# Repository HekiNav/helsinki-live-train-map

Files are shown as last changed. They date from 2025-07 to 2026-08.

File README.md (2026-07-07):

# Helsinki Live LED Train Map

A real-time PCB map of the Helsinki Region train network, powered by an ESP32-C3 microcontroller. Train movements are displayed using addressable RGB LEDs, with live data fetched over Wi-Fi.

---

## Table of Contents

- [Helsinki Live LED Train Map](#helsinki-live-led-train-map)
  - [Table of Contents](#table-of-contents)
  - [Features](#features)
  - [Hardware](#hardware)
  - [Design](#design)
  - [Software / Firmware](#software--firmware)
  - [Getting Started](#getting-started)
  - [Web Installer](#web-installer)
  - [Web Simulator](#web-simulator)
  - [Stand](#stand)
  - [Server](#server)
  - [Links](#links)
  - [Contributing](#contributing)
  - [License](#license)

---

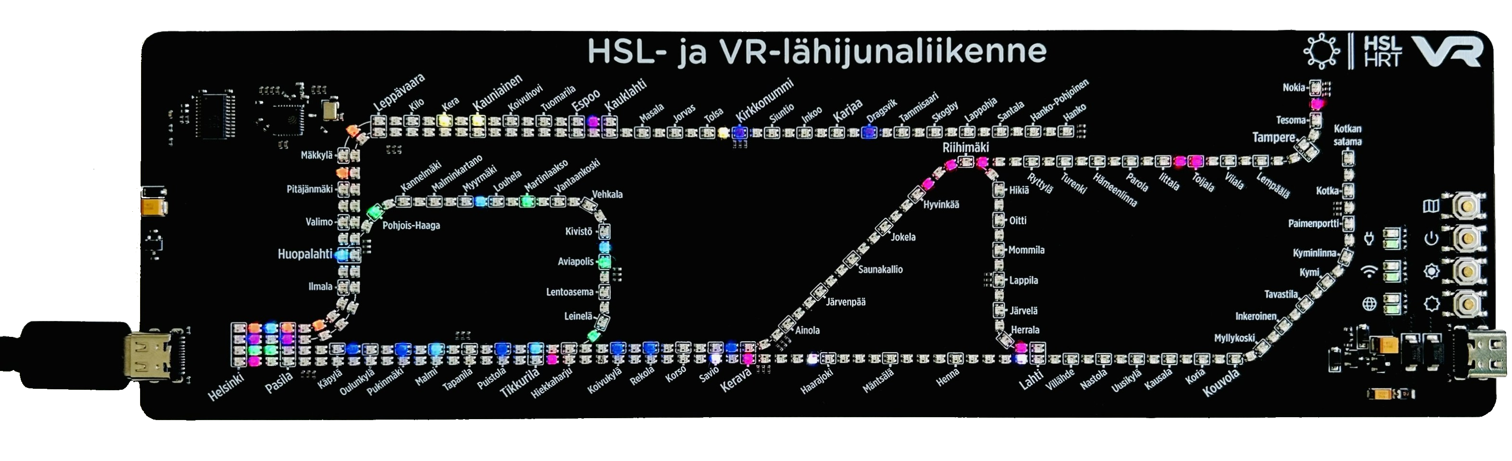
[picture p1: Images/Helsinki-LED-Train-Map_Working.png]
PCB Overview Render


## Features

- **Real-time Train Tracking:** Displays the approximate locations of trains on the HSL and VR commuter network.
- **Addressable LEDs:** ~290 WS2812B-compatible RGB LEDs (1.6x1.5mm) for a vibrant display.
- **Wi-Fi Connectivity:** ESP32-C3's built-in Wi-Fi fetches live train data.
- **Custom PCB:** Designed for JLCPCB manufacturing limits.
- **Open Source:** Hardware and firmware are open source.

---

## Hardware

- **Microcontroller:** Expressif ESP32-C3FH4 (RISC-V, 160 MHz, 4 MB Flash, QFN32)
- **Level shifter:** Texas Instruments SN74LVC4245APWR (3.3V to 5V)
- **LEDs:** ~290 x XingLight XL-1615RGBC-WS2812B (1.6mm x 1.5mm)
- **PCB:** 249mm x 71.5mm, JLCPCB-friendly
- **Antenna:** On-board PCB antenna ([TI CC2430DB design](https://www.ti.com/lit/ug/swru125/swru125.pdf))
- **Ports:** Two USB Type-C ports for redundancy

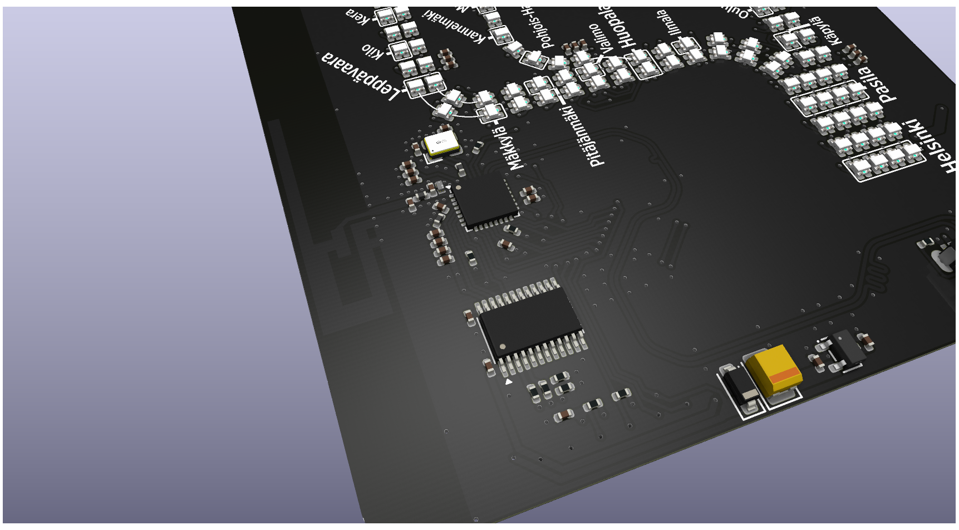
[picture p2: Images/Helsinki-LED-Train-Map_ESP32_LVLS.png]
ESP32-C3 PCB Render


---

## Design

### Rail diagram design

Inspiration for the layout was taken from the VR rail map used on commuter trains (above the doors). 

**Each LED represents a double-track line**
- 8-tracked sections (4 LEDs wide):
   1. Helsinki-Pasila
- Quad-tracked sections (2 express commuter & intercity, 2 slower commuter):
   1. Pasila-Leppävaara-(Kauklahti [Under construction])
   2. Pasila-Kerava

- Exceptions to single-track lines: 
   1. Tavastila-Kotkan satama
   2. Siuntio-Hanko

### Technical design

- Designed in **KiCad V9.0** using [JLCPCB KiCad Library](https://github.com/CDFER/jlcpcb-kicad-library)
- **View Online:** [Interactive PCB Layout (Kicanvas)](https://kicanvas.org/?github=https%3A%2F%2Fgithub.com%2FHekiNav%2Fhelsinki-live-train-map%2Ftree%2Fmain%2FPCB)
- **Source Files:** `/PCB` directory
### Schematic
Led chains are located on other pages

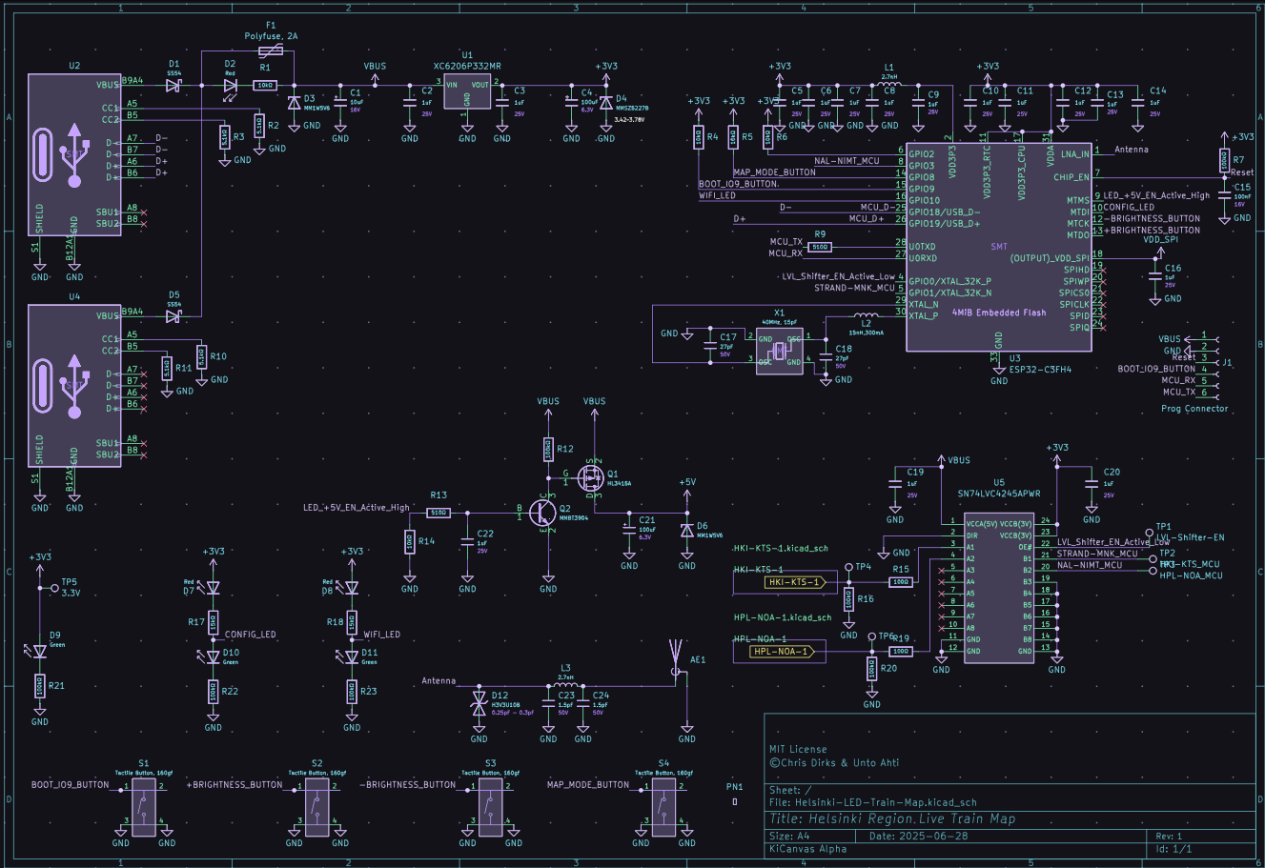
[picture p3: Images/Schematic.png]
Schematic


---

## Software / Firmware

NOTE! Software and firmware have been moved to [another repo](https://github.com/HekiNav/legacy-ltm-firmware)

The ESP32-C3 firmware is responsible for:

1. Connecting to Wi-Fi
2. Fetching live train data from the API
3. Processing data to determine train locations
4. Controlling WS2812B LED chains to display train positions
5. Handling button inputs and status LEDs
6. Hosting a web page for configuration

---

## Getting Started

1. **Flash the Firmware:**
   - Use the [Web Installer](#web-installer) (recommended, no drivers needed)
   - Or flash manually using PlatformIO (`Firmware/` directory)
2. **Connect to Wi-Fi:**
   - On first boot, use the web installer interface to configure Wi-Fi credentials. They are saved locally on the device.
3. **Power the Board:**
   - Use a 5V USB-C power supply capable of at least ~1A (~2A recommended for compatibility with higher brightness settings).
4. **Configure in the :**
   - Visit the IP address of your device (shown in Web Installer)
   - Configure options like tails, brightness and mode 
5. **Enjoy the Live Train Map!**

### Status LEDs

The top (🔌) power led is hardwired to the power rail

The middle and bottom status leds are controlled by the MCU

| LED | Light | Meaning |
|-----|---|---|
| top (🔌) |🟩 green | The board is powered
| top (🔌) |⬛ none  | The board is not powered
| top (🔌) |🟥 red | This shouldn't happen although it's techically possible if there's severe issues in the pcb
|||
| middle (ᯤ)  |🟩 green | Connected to the API
| middle (ᯤ)  |🟩 green \(blinking\) | Mode change pending
| middle (ᯤ)  |⬛ none | Connecting to the API
| middle (ᯤ)  |🟥 red | Failed to connect to API
|||
| bottom (🌐)  |🟩 green \(blinking\) | Connecting to wifi
| bottom (🌐)  |🟩 green | Connected to wifi
| bottom (🌐)  |⬛ none | Failed to boot
| bottom (🌐)  |🟥 red | Failed to connect to wifi

### Map Modes

There are 4(+1) map modes on the device. You can switch the mode by pressing the map (🗺️) button or by going to the control panel.

#### Lines (default)
- Shows commuter trains by line
- Only commuter trains
- Some colors are reused on lines that do not intersect

| Color | Line | |
|---|---|-|
|$${\color{#f00}\Huge\text{■}}$$| Z | |
|$${\color{#f80}\Huge\text{■}}$$| A | |
|$${\color{#ff0}\Huge\text{■}}$$| E,O | |
|$${\color{#0f0}\Huge\text{■}}$$| P,G | |
|$${\color{#0ff}\Huge\text{■}}$$| M,I | |
|$${\color{#00f}\Huge\text{■}}$$| K | |
|$${\color{#80f}\Huge\text{■}}$$| Y,L,H | |
|$${\color{#f0f}\Huge\text{■}}$$| U | |
|$${\color{#f08}\Huge\text{■}}$$| D,T,R | |
|$${\color{#fff}\Huge\text{■}}$$| V, Other | Look up on [juliadata.fi](https://juliadata.fi/map/view?mode=trains#8.86/60.3487/25.1733)|

\* V is used in transfer services

#### Delay
- Shows the delay state of trains
- Only commuter trains

| Color | Delay (min) | Description |
|---|---|---|
|$${\color{#0ff}\Huge\text{■}}$$| < 0 | Ahead of schedule |  
|$${\color{#0f0}\Huge\text{■}}$$| 0 - 2 | On time |
|$${\color{#ff0}\Huge\text{■}}$$| 2 - 10 | Mild delay |
|$${\color{#f00}\Huge\text{■}}$$| > 20 | Severe delay |
|$${\color{#f0f}\Huge\text{■}}$$| - | Unknown delay amount |

#### Composition
- Shows the locomotives/EMUs of trains
- ALL trains shown (incl. InterCity, freight)

| Color | Loco | Description |
|---|---|---|
| EMUs | | |
|$${\color{#f00}\Huge\text{■}}$$| [Sm2](https://fi.wikipedia.org/wiki/Sm2) | Commuter, old |
|$${\color{#0f0}\Huge\text{■}}$$| [Sm3](https://fi.wikipedia.org/wiki/Sm3) | Pendolino (IC) |
|$${\color{#ff0}\Huge\text{■}}$$| [Sm4](https://fi.wikipedia.org/wiki/Sm4) | Commuter, longer distances |
|$${\color{#80f}\Huge\text{■}}$$| [Sm5](https://fi.wikipedia.org/wiki/Sm5) | Commuter, shorter distances |
|$${\color{#f0f}\Huge\text{■}}$$| [Sm6](https://fi.wikipedia.org/wiki/Sm6) | Allegro (IC) |
|$${\color{#f80}\Huge\text{■}}$$| [Sm7](https://fi.wikipedia.org/wiki/Sm7) | Commuter, not in regular service yet |
| Locos | | |
|$${\color{#0ff}\Huge\text{■}}$$| [Sr2](https://fi.wikipedia.org/wiki/Sr2) | IC locomotive |
|$${\color{#00f}\Huge\text{■}}$$| [Sr3](https://fi.wikipedia.org/wiki/Sr3) | Newer IC locomotive |
| Other | | |
|$${\color{#f08}\Huge\text{■}}$$| N/A | No composition found (most likely freight) |
|$${\color{#fff}\Huge\text{■}}$$| Other | Other locomotive with no color defined (Look up on [juliadata.fi](https://juliadata.fi/map/view?mode=trains#8.86/60.3487/25.1733)) |

#### Train types
- Shows the types of trains
- ALL trains shown (incl. InterCity, freight)

| Color | Code | Description |
|---|---|---|
|$${\color{#f00}\Huge\text{■}}$$| IC | Double-decker intercity trains |
|$${\color{#f80}\Huge\text{■}}$$| VET | Locomotive train |
|$${\color{#f80}\Huge\text{■}}$$| MUS, MUV | Heritage train |
|$${\color{#0f0}\Huge\text{■}}$$| S | Pendolino train |
|$${\color{#00f}\Huge\text{■}}$$| T | Freight train |
|$${\color{#80f}\Huge\text{■}}$$| HL | Commuter train |
|$${\color{#f0f}\Huge\text{■}}$$| HV | Commuter train transfer |
|$${\color{#f08}\Huge\text{■}}$$| PAR, PAI, VEV, W, SAA | Shunting |
|$${\color{#fff}\Huge\text{■}}$$| Other | Other train type with no color defined (Look up on [juliadata.fi](https://juliadata.fi/map/view?mode=trains#8.86/60.3487/25.1733)) |

#### Test
- Shows the types of LEDs

| Color | Type | Description | Technical logic |
|---|---|---|---|
|$${\color{#ff0}\Huge\text{■}}$$| Station | All services stop | Train has arrived, but not departed |
|$${\color{#f00}\Huge\text{■}}$$| Stop | Express services skip | Same as station |
|$${\color{#0f0}\Huge\text{■}}$$| Between | Single LED between stops/stations | Train left previous, not arrived at next |
|$${\color{#0ff}\Huge\text{■}}$$| MultiBetween | Multiple LEDs between stops/stations | Same as between, but exact position is appoximated using timetable |

#### Disruptions
- Shows disruptions for stations and trains

| Color | Disruption |
|---|---|
|$${\color{#f00}\Huge\text{■}}$$| Cancellation |
|$${\color{#f80}\Huge\text{■}}$$| Infrastructure disruption |
|$${\color{#ff0}\Huge\text{■}}$$| Other disruption |
|$${\color{#0f0}\Huge\text{■}}$$| Track work |
|$${\color{#0ff}\Huge\text{■}}$$| Private train |
|$${\color{#00f}\Huge\text{■}}$$| Replacement service |
|$${\color{#80f}\Huge\text{■}}$$| Missing/replaced wagon(s) |
|$${\color{#fff}\Huge\text{■}}$$| Unclassified |

---

## Web Installer

Easily flash the latest firmware to your ESP32-C3 using your browser:

[Open the Helsinki LED Train Map Web Installer](https://hekinav.github.io/ltm-firmware/led-rails.html)

- Works with Chrome, Edge, or any Web Serial-compatible browser
- Follow on-screen instructions to connect and flash your device

---

## Web Simulator

View the map without having the physical pcb:

[Open the Helsinki LED Train Map Web Simulator](https://hekinav.github.io/ltm-firmware/sim.html)

- Use the map mode button to switch display modes, just like on the real thing
- Works with most modern browsers
- Fetches data from the API

---
## Stand and other 3D Models

A 3d-printable stand to hold up the board. Files are located in `/3D Models`

---

## Server

Processes train running data from [digitraffic](https://rata.digitraffic.fi/). Documentation for the train API is available at https://www.digitraffic.fi/rautatieliikenne. Most of it is only available in finnish.

### Main packages:
- express: API handling
- mqtt: Listening to MQTT train messages 
- node-sqlite & sqlite3: Database for cached train compositions and stats
- node-cron: Cron jobs for recaching data and cleaning the database

The api is tunneled to [ltm.hekinav.dev](https://ltm.hekinav.dev/).

### Running locally

Install npm packages

`npm install`

Start the api in dev mode (watches files) (uses port 3001 by default)

`npm run dev`

### Production

Compile TS to JS

`npm run build`

Start the server

`npm run start` or in PM2 `pm2 start ./ecosystem.config.cjs`

---

## Links

- [Web Installer](https://hekinav.github.io/ltm-firmware//led-rails.html)
- [Web Simulator](https://hekinav.github.io/ltm-firmware//sim.html)
- [Interactive PCB Viewer](https://kicanvas.org/?github=https%3A%2F%2Fgithub.com%2FHekiNav%2Fhelsinki-live-train-map%2Ftree%2Fmain%2FPCB)
- [JLCPCB KiCad Library](https://github.com/CDFER/jlcpcb-kicad-library)

---

## Contributing

Contributions are welcome! Open an issue or submit a pull request for improvements, bug fixes, or feature suggestions.

---

## Attributions

Thanks to [Chris (CDFER)](https://github.com/CDFER/) for the base and support of this project. Check out his store with multiple LED Rail Maps at [keastudios.co.nz](https://keastudios.co.nz/)

## License

This project is released under the MIT license.

© 2025 Chris Dirks & Unto Ahti

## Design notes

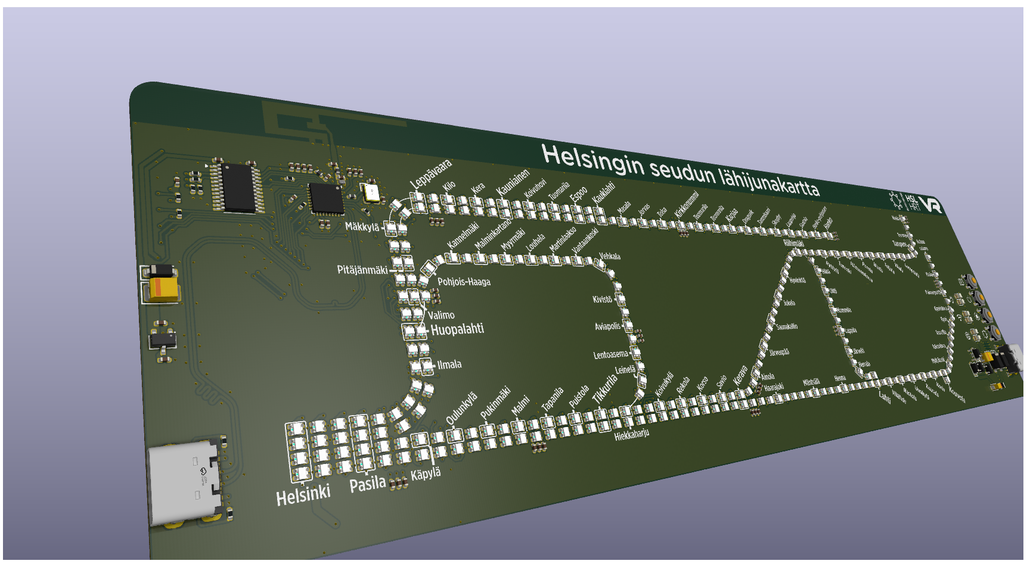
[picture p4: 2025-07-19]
Images/Helsinki-LED-Train-Map_Overview.png

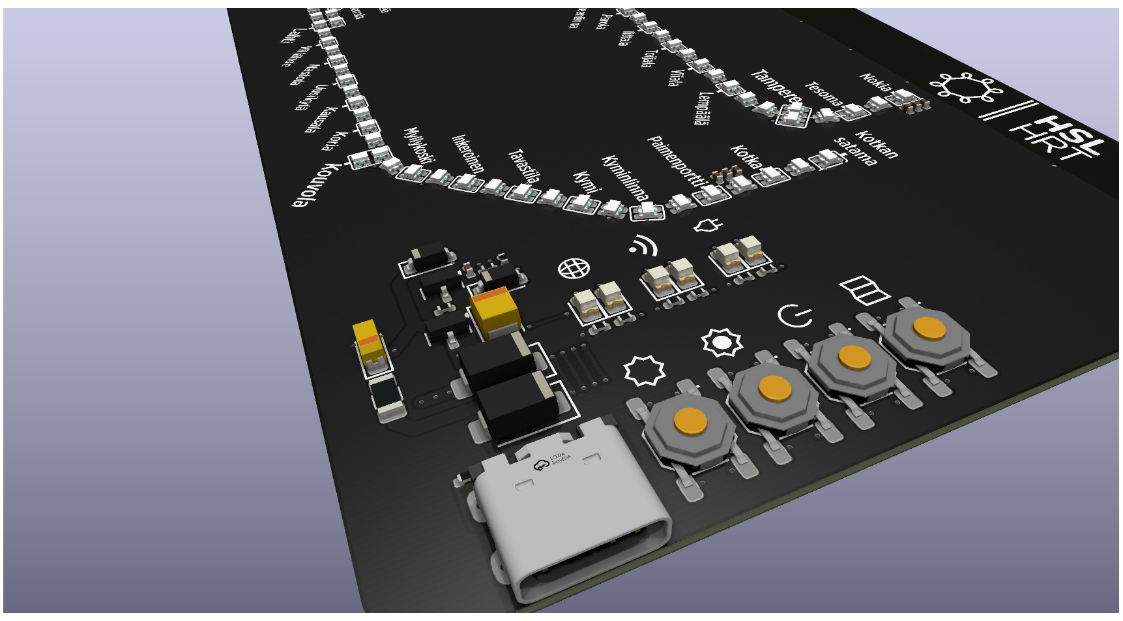
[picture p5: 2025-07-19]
Images/Helsinki-LED-Train-Map_BTNS_PWR.png

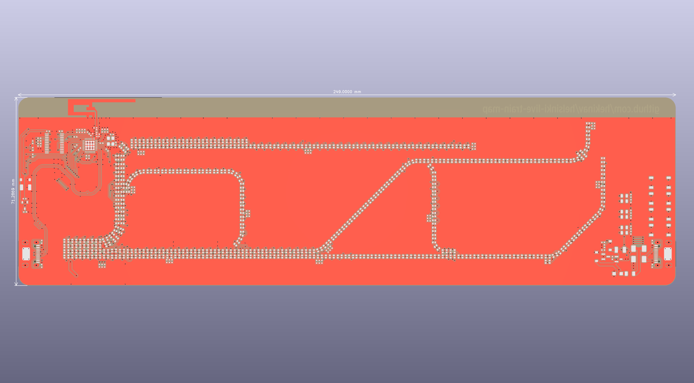
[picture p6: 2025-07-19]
Images/Helsinki-LED-Train-Map_F_CU.png

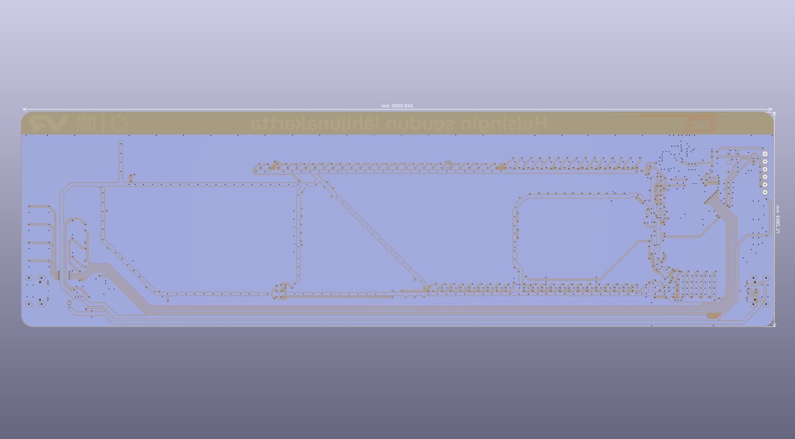
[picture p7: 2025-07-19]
Images/Helsinki-LED-Train-Map_B_CU.png

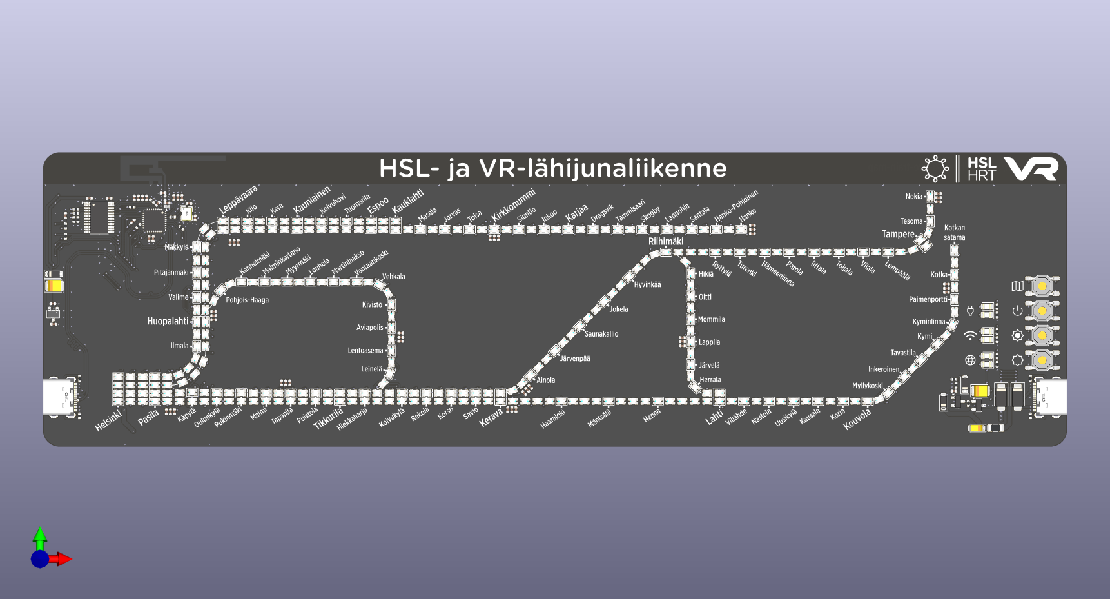
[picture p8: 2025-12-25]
PCB/Helsinki-LED-Train-Map.png

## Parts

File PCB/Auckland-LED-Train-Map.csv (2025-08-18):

Reference | Qty | Minimum Qty | Attrition Qty | Manufacturer | Part | Description | Value | Footprint | LCSC | Price | Process
D13,D14,D15,D16,D17,D18,D19,D20,D21,D22,D23,D24,D25,D26,D27,D28,D29,D30,D31,D32,D34,D35,D36,D37,D38,D39,D40,D41,D42,D43,D44,D45,D46,D47,D48,D49,D50,D52,D53,D54,D55,D56,D57,D58,D59,D60,D61,D62,D63,D64,D65,D66,D67,D68,D69,D70,D71,D72,D73,D74,D75,D76,D77,D78,D79,D80,D81,D82,D83,D84,D85,D86,D87,D88,D89,D90,D91,D92,D93,D94,D95,D96,D97,D98,D99,D100,D101,D102,D103,D104,D105,D106,D107,D108,D109,D110,D111,D112,D113,D114,D115,D116,D117,D118,D119,D120,D121,D122,D123,D124,D125,D126,D127,D128,D129,D130,D131,D132,D133,D134,D135,D136,D137,D138,D139,D140,D141,D142,D143,D144,D145,D146,D147,D148,D149,D150,D151,D152,D153,D154,D155,D156,D157,D158,D159,D160,D161,D162,D163,D164,D165,D166,D167,D168,D169,D170,D171,D172,D173,D174,D175,D176,D177,D178,D179,D180,D181,D182,D183,D184,D185,D186,D187,D188,D189,D190,D191,D192,D193,D194,D195,D196,D197,D198,D199,D200,D201,D202,D203,D204,D205,D206,D207,D208,D209,D210,D211,D212,D213,D214,D215,D216,D217,D218,D219,D220,D221,D222,D223,D224,D225,D226,D227,D228,D229,D230,D231,D232,D233,D234,D235,D236,D237,D238,D239,D240,D241,D242,D243,D244,D245,D246,D247,D248,D249,D250,D251,D252,D253,D254,D255,D256,D257,D258,D259,D260,D261,D262,D263,D264,D265,D266,D267,D268,D269,D270,D271,D272,D273,D274,D275,D276,D277,D278,D279,D281,D282,D283,D284,D285,D286,D287,D288,D289,D290,D291,D292,D293,D294,D295,D296,D297,D298,D299,D300,D301,D302,D303 | 288 |  |  | XINGLIGHT | XL-1615RGBC-WS2812B | 1615 RGB LEDs(Built-in IC) ROHS | WS2812B | PCM_JLCPCB:LED-SMD_4P-L1.6-W1.5_XL-1615RGBC-WS2812B | C5349954 |  | SMT
C2,C3,C5,C6,C7,C8,C9,C10,C11,C12,C13,C14,C16,C19,C20,C22,C25,C26,C27,C28,C29,C30,C31,C32,C33,C34,C35,C36,C37,C38,C39,C40,C41,C42,C43,C44,C45,C46,C47,C48,C49,C50,C51,C52,C53,C54,C55,C56,C57,C58,C59,C60 | 52 | 20 | 10 | Samsung Electro-Mechanics | CL05A105KA5NQNC | 25V 1uF X5R ±10% 0402 Multilayer Ceramic Capacitors MLCC - SMD/SMT ROHS | 1uF | PCM_JLCPCB:C_0402 | C52923 | 0.006USD | SMT
R7,R12,R16,R20,R21,R22,R23 | 7 | 20 | 10 | UNI-ROYAL(Uniroyal Elec) | 0402WGF1003TCE | 62.5mW Thick Film Resistors 50V ±100ppm/°C ±1% 100kΩ 0402 Chip Resistor - Surface Mount ROHS | 100kΩ | PCM_JLCPCB:R_0402 | C25741 | 0.004USD | SMT
R1,R4,R5,R6,R14 | 5 | 20,5 | 0,10 | UNI-ROYAL(Uniroyal Elec) | 0402WGF1002TCE | 62.5mW Thick Film Resistors 50V ±100ppm/°C ±1% 10kΩ 0402 Chip Resistor - Surface Mount ROHS | 10kΩ | PCM_JLCPCB:R_0402 | C25744 | 0.004USD | SMT
S1,S2,S3,S4 | 4 | 10 | 5 | XKB Connectivity | TS-1187A-B-A-B | None Without 50mA 5.1mm 100000 Times 160gf 12V 5.1mm 1.5mm Round Button Standing paste SPST SMD Tactile Switches ROHS | Tactile Button, 160gf | PCM_JLCPCB:SW-SMD_4P-L5.1-W5.1-P3.70-LS6.5-TL-2 | C318884 | 0.025USD | SMT
R2,R3,R10,R11 | 4 | 20 | 10 | UNI-ROYAL(Uniroyal Elec) | 0402WGF5101TCE | 62.5mW Thick Film Resistors 50V ±100ppm/°C ±1% 5.1kΩ 0402 Chip Resistor - Surface Mount ROHS | 5.1kΩ | PCM_JLCPCB:R_0402 | C25905 | 0.004USD | SMT
D9,D10,D11 | 3 | 20 | 6 | Hubei KENTO Elec | KT-0805G | Emerald 0805 LED Indication - Discrete ROHS | Green | PCM_JLCPCB:D_0805 | C2297 | 0.014USD | SMT
D2,D7,D8 | 3 | 20 | 6 | Foshan NationStar Optoelectronics | NCD0805R1 | 25mA Colorless transparent lens 67mcd~195mcd -30°C~+85°C 615nm~630nm Individual diode Red 130° 65mW 1.6V~2.6V 0805 LED Indication - Discrete ROHS | Red | PCM_JLCPCB:D_0805 | C84256 | 0.016USD | SMT
U2,U4 | 2 |  |  | DEALON | USB-TYPE-C-019 | 3A 1 Horizontal attachment 16P Female -25℃~+85℃ Type-C SMD USB Connectors ROHS | Connector, USB-TYPE-C-16P | PCM_JLCPCB:TYPE-C-SMD_HX-TYPE-C-16PIN | C2927039 |  | SMT
R17,R18 | 2 | 20 | 10 | UNI-ROYAL(Uniroyal Elec) | 0402WGF1502TCE | 62.5mW Thick Film Resistors 50V ±100ppm/°C ±1% 15kΩ 0402 Chip Resistor - Surface Mount ROHS | 15kΩ | PCM_JLCPCB:R_0402 | C25756 | 0.004USD | SMT
R15,R19 | 2 | 20 | 10 | UNI-ROYAL(Uniroyal Elec) | 0402WGF1000TCE | 62.5mW Thick Film Resistors 50V ±1% ±200ppm/°C 100Ω 0402 Chip Resistor - Surface Mount ROHS | 100Ω | PCM_JLCPCB:R_0402 | C25076 | 0.004USD | SMT
R9,R13 | 2 | 20 | 10,12 | UNI-ROYAL(Uniroyal Elec) | 0402WGF5100TCE | 62.5mW Thick Film Resistors 50V ±100ppm/°C ±1% 510Ω 0402 Chip Resistor - Surface Mount ROHS | 510Ω | PCM_JLCPCB:R_0402 | C25123 | 0.004USD | SMT
L1,L3 | 2 |  |  | Murata Electronics | LQG15HS2N7S02D | 800mA 2.7nH 120mΩ 0402 Inductors (SMD) ROHS | 2.7nH | PCM_JLCPCB:L_0402 | C77108 |  | SMT
D3,D6 | 2 | 5 | 4 | hongjiacheng | MM1W5V6 | Independent Type 5.32V~5.92V 1W 5.6V SOD-123 Zener Diodes ROHS | MM1W5V6 | PCM_JLCPCB:D_SOD-123 | C22435086 | 0.037USD | SMT
D1,D5 | 2 | 5 | 4 | MDD（Microdiode Electronics） | SS54 | 40V Independent Type 550mV@5A 5A SMA(DO-214AC) Schottky Diodes ROHS | SS54 | PCM_JLCPCB:D_SMA | C22452 | 0.043USD | SMT
C23,C24 | 2 | 20 | 10 | FH(Guangdong Fenghua Advanced Tech) | 0402CG1R5C500NT | 50V 1.5pF C0G 0402 Multilayer Ceramic Capacitors MLCC - SMD/SMT ROHS | 1.5pF | PCM_JLCPCB:C_0402 | C1552 | 0.004USD | SMT
C17,C18 | 2 | 20 | 10 | FH(Guangdong Fenghua Advanced Tech) | 0402CG270J500NT | 50V 27pF C0G ±5% 0402 Multilayer Ceramic Capacitors MLCC - SMD/SMT ROHS | 27pF | PCM_JLCPCB:C_0402 | C1557 | 0.004USD | SMT
C4,C21 | 2 | 5 | 2 | AVX | TAJB107K006RNJ | 100uF 6.3V 1.7Ω@100kHz ±10% CASE-B-3528-21(mm) Tantalum Capacitors ROHS | 100uF | PCM_JLCPCB:C_CASE-B-3528-21(mm) | C16133 | 0.161USD | SMT
X1 | 1 |  |  | YXC Crystal Oscillators | X322540MPB4SI | 40MHz Surface Mount Crystal 15pF ±10ppm ±20ppm SMD3225-4P Crystals ROHS | 40MHz, 15pF | Custom_Footprints:OSC-SMD_4P-L3.2-W2.5-BL_SIT8008BI | C9010 |  | SMT
U5 | 1 | 1 | 0 | Texas Instruments | SN74LVC4245APWR | 2.7V~3.6V 1 8 4.5V~5.5V TSSOP-24 Translators, Level Shifters ROHS | SN74LVC4245APWR | Package_SO:TSSOP-24_4.4x7.8mm_P0.65mm | C7859 | 0.196USD | SMT
U3 | 1 |  |  | Espressif Systems | ESP32-C3FH4 | RF Module, ESP32 SoC, RISC-V, WiFi 802.11b/n/g, Bluetooth LE 5, QFN32 | ESP32-C3FH4 | Custom_Footprints:QFN-32-1EP_5x5mm_P0.5mm_EP3.7x3.7mm_ThermalVias | C2858491 |  | SMT
U1 | 1 | 5 | 2 | Torex Semicon | XC6206P332MR-G | 200mA Fixed 3.3V Positive electrode 6V SOT-23-3L Voltage Regulators - Linear, Low Drop Out (LDO) Regulators ROHS | XC6206P332MR | PCM_JLCPCB:SOT-23-3_L2.9-W1.6-P1.90-LS2.8-BR | C5446 | 0.093USD | SMT
Q2 | 1 | 10 | 5 | hongjiacheng | MMBT3904 | 40V 200mW 100@10mA,1.0V 200mA NPN SOT-23 Bipolar (BJT) ROHS | MMBT3904 | PCM_JLCPCB:Q_SOT-23 | C7420353 | 0.012USD | SMT
Q1 | 1 | 5 | 4 | hongjiacheng | HL3415A | 20V 5.6A 42mΩ@4.5V,5A 1.3W 620mV@250uA 1 Piece P-Channel SOT-23 MOSFETs ROHS | HL3415A | PCM_JLCPCB:Q_SOT-23 | C28646270 | 0.040USD | SMT
L2 | 1 | 20 | 10 | Sunlord | SDCL1005C15NJTDF | 8@100MHz ±5% 0402 Inductors (SMD) | 15nH,300mA | PCM_JLCPCB:L_0402 | C27143 | 0.007USD | SMT
F1 | 1 |  |  |  |  |  | Polyfuse, 2A | Fuse:Fuse_1206_3216Metric | C6165195 |  | SMT
D12 | 1 | 20 | 8 | hongjiacheng | H3V3U10B | 5A 25V 125W 9V Bidirectional 3.3V DFN1006-2L ESD and Surge Protection (TVS/ESD) ROHS | H3V3U10B | PCM_JLCPCB:D_DFN1006-2L | C20615782 | 0.030USD | SMT
D4 | 1 | 15 | 4 | hongjiacheng | MMSZ5227B | Independent Type 3.42V~3.78V 500mW 3.6V SOD-123 Zener Diodes ROHS | MMSZ5227B | PCM_JLCPCB:D_SOD-123 | C22395553 | 0.021USD | SMT
C15 | 1 | 20 | 10 | Samsung Electro-Mechanics | CL05B104KO5NNNC | 16V 100nF X7R ±10% 0402 Multilayer Ceramic Capacitors MLCC - SMD/SMT ROHS | 100nF | PCM_JLCPCB:C_0402 | C1525 | 0.004USD | SMT
C1 | 1 | 5 | 2 | AVX | TAJA106K016RNJ | 10uF 16V 3Ω@100kHz ±10% CASE-A-3216-18(mm) Tantalum Capacitors ROHS | 10uF | PCM_JLCPCB:C_CASE-A-3216-18(mm) | C7171 | 0.151USD | SMT

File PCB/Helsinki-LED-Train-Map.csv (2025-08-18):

Id | Designator | Footprint | Quantity | Designation | Supplier and ref
1 | D215,D255,D165,D45,D242,D98,D75,D120,D296,D49,D26,D291,D68,D187,D243,D268,D108,D159,D85,D208,D127,D192,D107,D256,D17,D102,D287,D225,D50,D303,D264,D190,D194,D29,D92,D96,D227,D171,D148,D110,D133,D103,D265,D258,D77,D284,D293,D104,D172,D281,D27,D93,D73,D272,D54,D74,D81,D262,D175,D249,D14,D253,D76,D301,D58,D39,D289,D240,D97,D288,D219,D166,D299,D67,D203,D168,D197,D22,D223,D237,D180,D69,D134,D106,D156,D149,D297,D283,D80,D157,D30,D263,D132,D21,D278,D20,D116,D210,D141,D224,D233,D234,D266,D167,D135,D34,D137,D47,D239,D99,D241,D53,D109,D55,D31,D179,D131,D88,D269,D122,D221,D15,D230,D298,D183,D18,D160,D28,D216,D220,D250,D79,D199,D48,D274,D226,D186,D60,D42,D228,D56,D35,D174,D147,D151,D32,D207,D100,D89,D244,D252,D112,D24,D212,D162,D177,D136,D65,D204,D169,D300,D184,D261,D277,D178,D229,D52,D83,D155,D222,D200,D130,D23,D115,D302,D282,D78,D61,D247,D217,D248,D57,D126,D71,D294,D198,D64,D185,D59,D295,D144,D146,D128,D275,D154,D94,D38,D16,D95,D246,D86,D170,D129,D286,D150,D270,D145,D139,D158,D259,D43,D70,D143,D182,D201,D125,D218,D161,D114,D63,D181,D25,D117,D13,D101,D211,D37,D138,D119,D290,D87,D113,D257,D164,D140,D191,D232,D189,D254,D231,D196,D163,D153,D36,D202,D111,D152,D251,D41,D72,D82,D142,D195,D260,D238,D193,D19,D188,D66,D292,D209,D267,D273,D176,D40,D214,D245,D235,D276,D46,D213,D121,D105,D205,D173,D62,D90,D285,D206,D271,D118,D44,D91,D84,D123,D236,D124,D279 | LED-SMD_4P-L1.6-W1.5_XL-1615RGBC-WS2812B | 288 | WS2812B
2 | Q1 | Q_SOT-23 | 1 | HL3415A
3 | C39,C36,C16,C26,C41,C12,C44,C42,C32,C47,C45,C30,C3,C8,C6,C50,C51,C10,C31,C56,C43,C25,C54,C33,C13,C5,C60,C48,C40,C9,C29,C28,C49,C7,C57,C35,C55,C14,C11,C2,C20,C59,C22,C53,C38,C34,C19,C37,C58,C46,C52,C27 | C_0402 | 52 | 1uF
4 | R4,R14,R5,R6,R1 | R_0402 | 5 | 10kΩ
5 | C23,C24 | C_0402 | 2 | 1.5pF
6 | D3,D6 | D_SOD-123 | 2 | MM1W5V6
7 | D2,D7,D8 | D_0805 | 3 | Red
8 | R12,R7,R16,R23,R20,R22,R21 | R_0402 | 7 | 100kΩ
9 | L1,L3 | L_0402 | 2 | 2.7nH
10 | C4,C21 | C_CASE-B-3528-21(mm) | 2 | 100uF
11 | U3 | QFN-32-1EP_5x5mm_P0.5mm_EP3.7x3.7mm_ThermalVias | 1 | ESP32-C3FH4
12 | D9,D11,D10 | D_0805 | 3 | Green
13 | S4,S3,S2,S1 | SW-SMD_4P-L5.1-W5.1-P3.70-LS6.5-TL-2 | 4 | Tactile Button, 160gf
14 | L2 | L_0402 | 1 | 15nH,300mA
15 | D4 | D_SOD-123 | 1 | MMSZ5227B
16 | U1 | SOT-23-3_L2.9-W1.6-P1.90-LS2.8-BR | 1 | XC6206P332MR
17 | D1,D5 | D_SMA | 2 | SS54
18 | U5 | TSSOP-24_4.4x7.8mm_P0.65mm | 1 | SN74LVC4245APWR
19 | R9,R13 | R_0402 | 2 | 510Ω
20 | R17,R18 | R_0402 | 2 | 15kΩ
21 | Q2 | Q_SOT-23 | 1 | MMBT3904
22 | R3,R2,R10,R11 | R_0402 | 4 | 5.1kΩ
23 | D12 | D_DFN1006-2L | 1 | H3V3U10B
24 | R19,R15 | R_0402 | 2 | 100Ω
25 | C15 | C_0402 | 1 | 100nF
26 | U4,U2 | TYPE-C-SMD_HX-TYPE-C-16PIN | 2 | Connector, USB-TYPE-C-16P
27 | C1 | C_CASE-A-3216-18(mm) | 1 | 10uF
28 | C18,C17 | C_0402 | 2 | 27pF
29 | X1 | OSC-SMD_4P-L3.2-W2.5-BL_SIT8008BI | 1 | 40MHz, 15pF
30 | F1 | Fuse_1206_3216Metric | 1 | Polyfuse, 2A

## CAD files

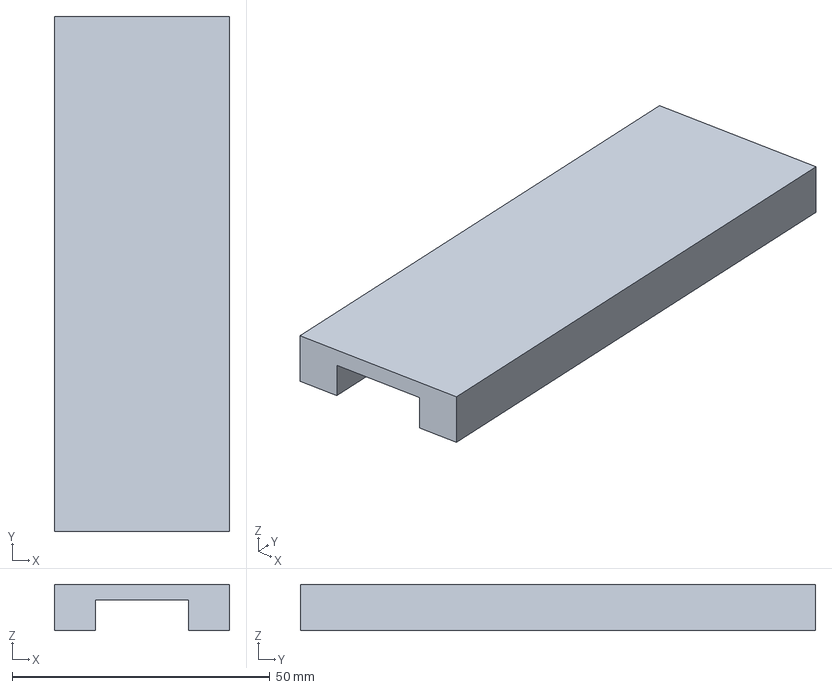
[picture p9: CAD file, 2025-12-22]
3D Models/XL1615-WS2812B_diffuser.FCStd
34.0 x 100.0 x 9.00 mm

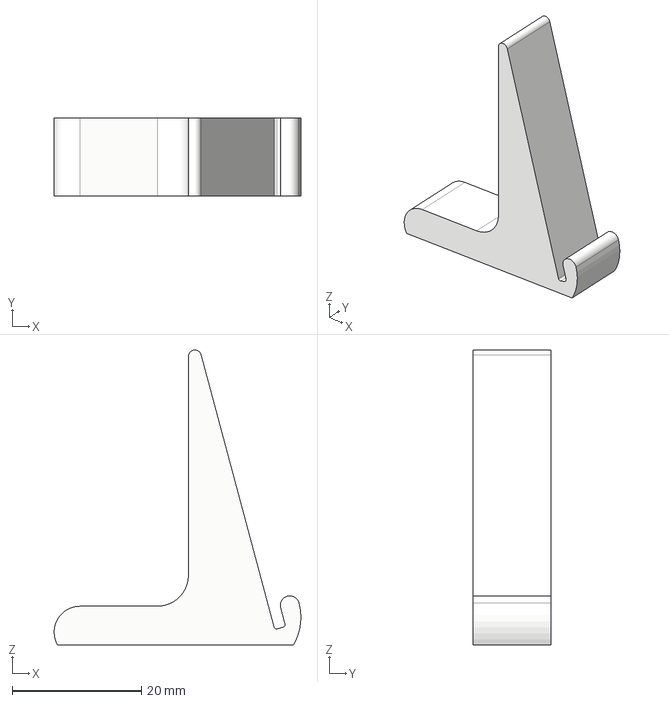
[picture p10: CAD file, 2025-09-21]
3D Models/ltm_stand.step
38.2 x 12.0 x 45.6 mm

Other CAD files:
PCB/Unnamed-Helsinki-LED-Train-Map.obj
3D Models/XL1615-WS2812B_diffuser.3mf
3D Models/ltm_stand.3mf
3D Models/pcb.blend

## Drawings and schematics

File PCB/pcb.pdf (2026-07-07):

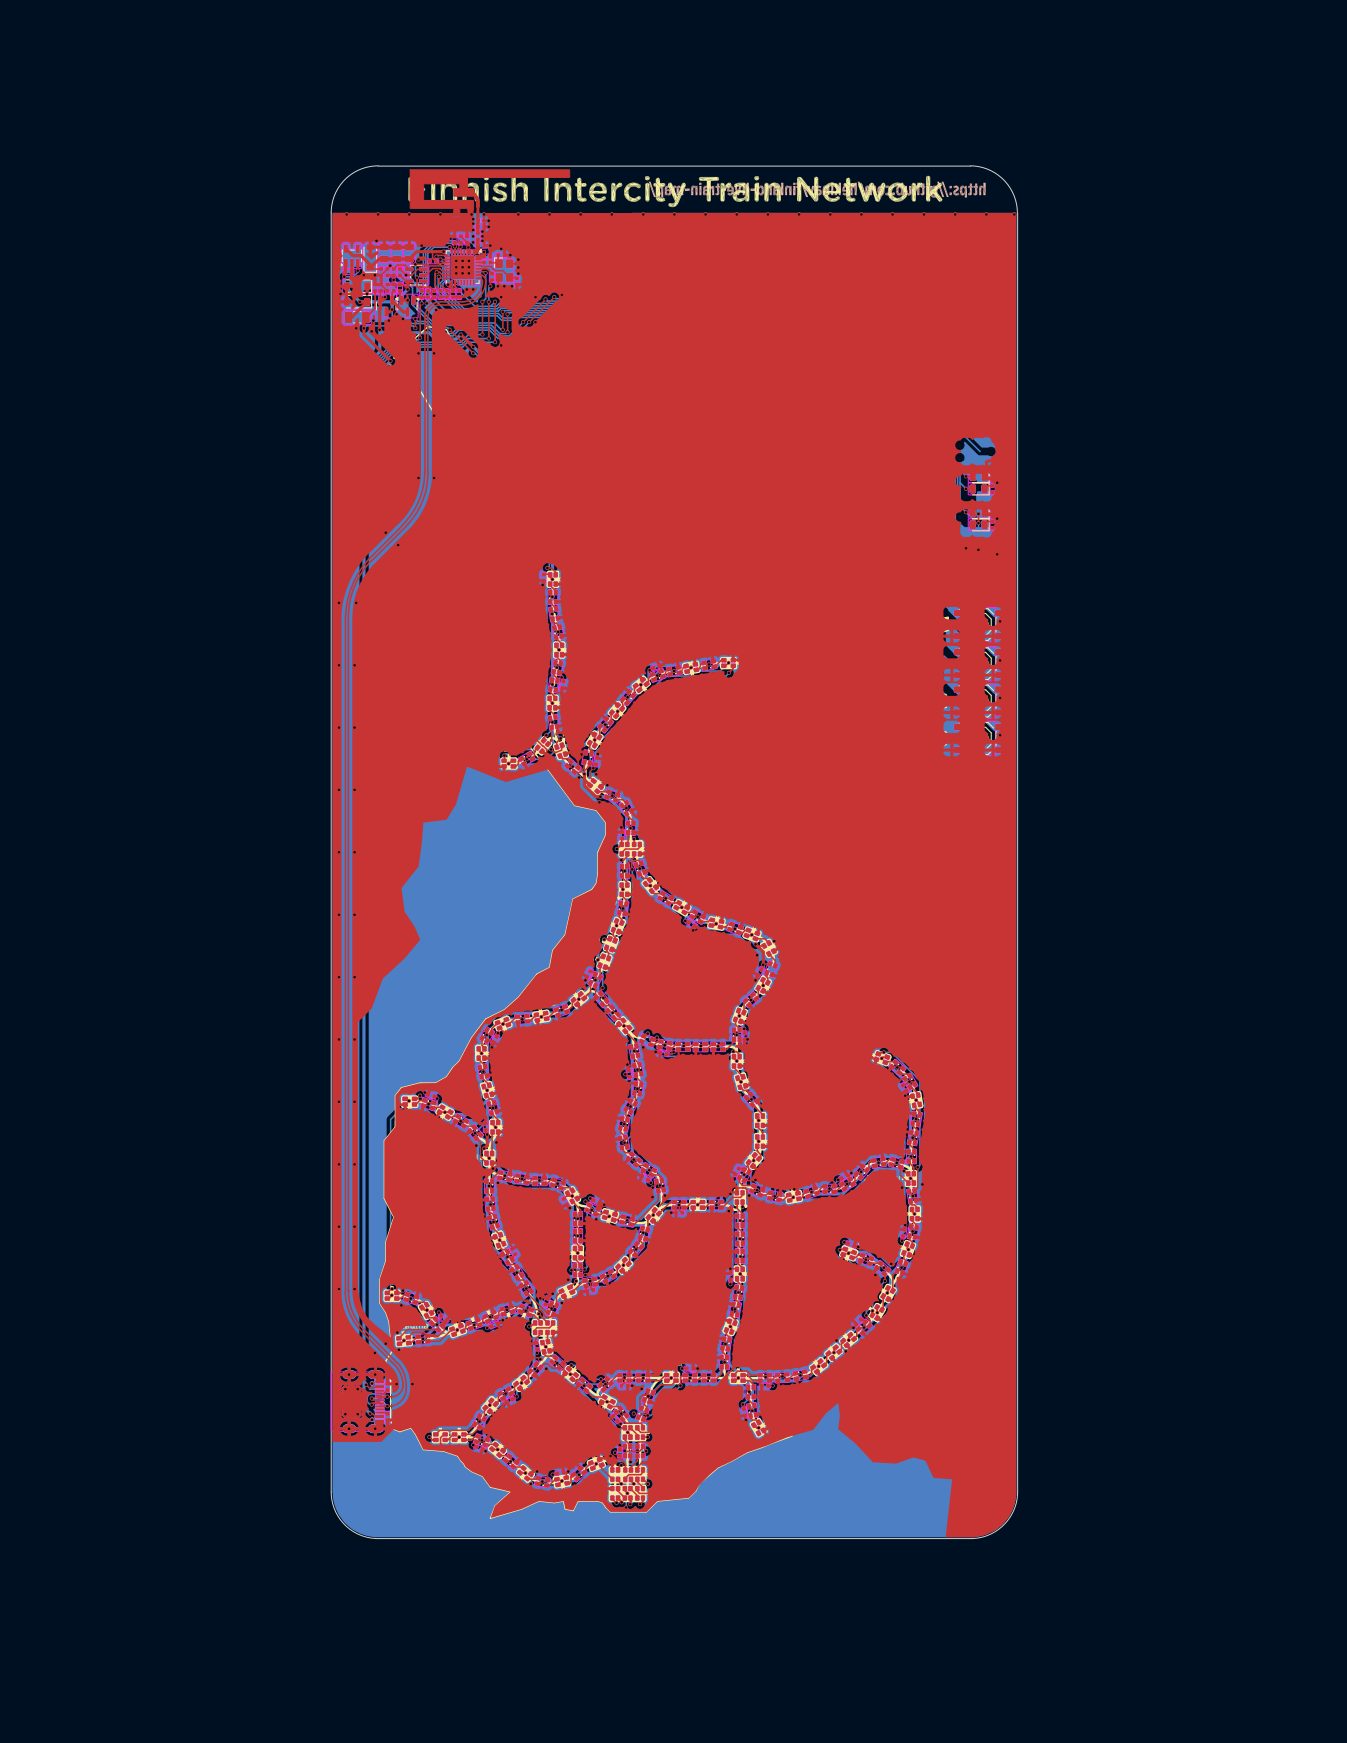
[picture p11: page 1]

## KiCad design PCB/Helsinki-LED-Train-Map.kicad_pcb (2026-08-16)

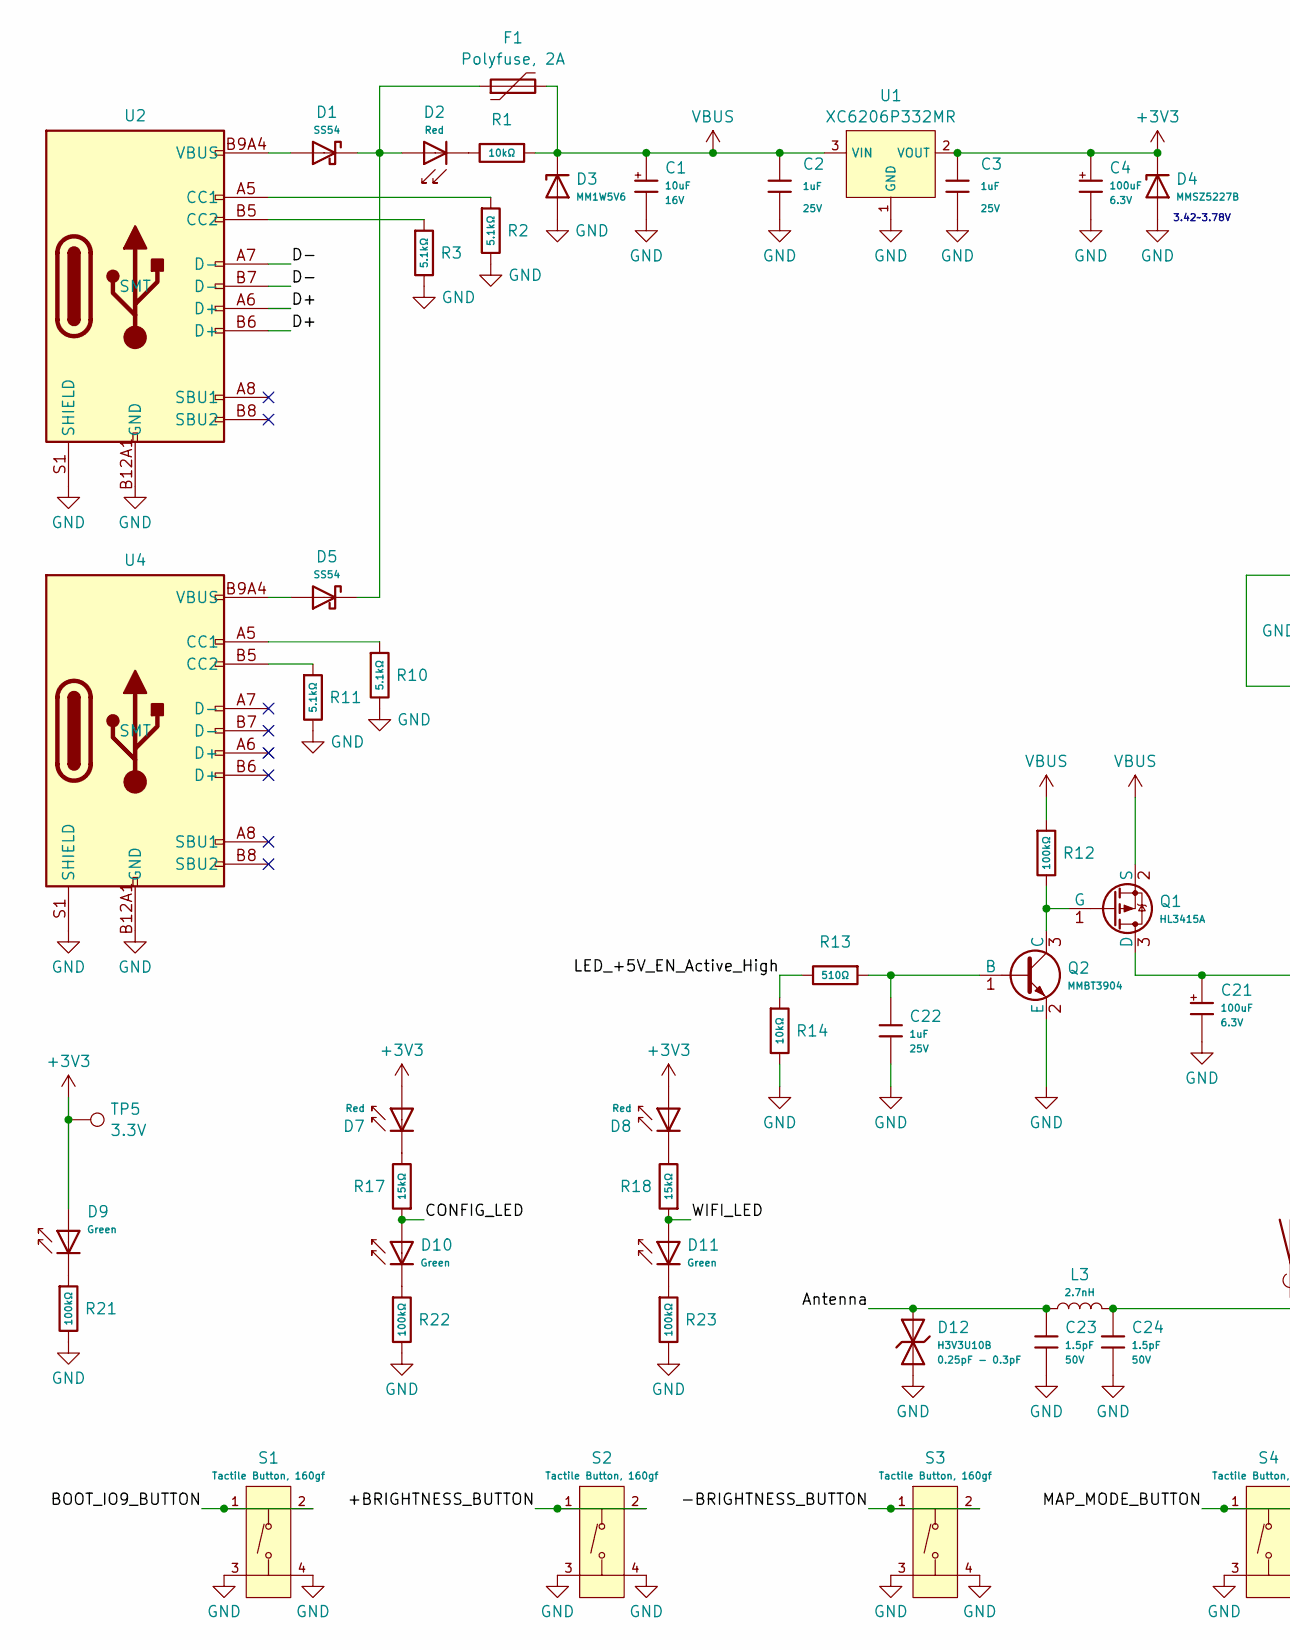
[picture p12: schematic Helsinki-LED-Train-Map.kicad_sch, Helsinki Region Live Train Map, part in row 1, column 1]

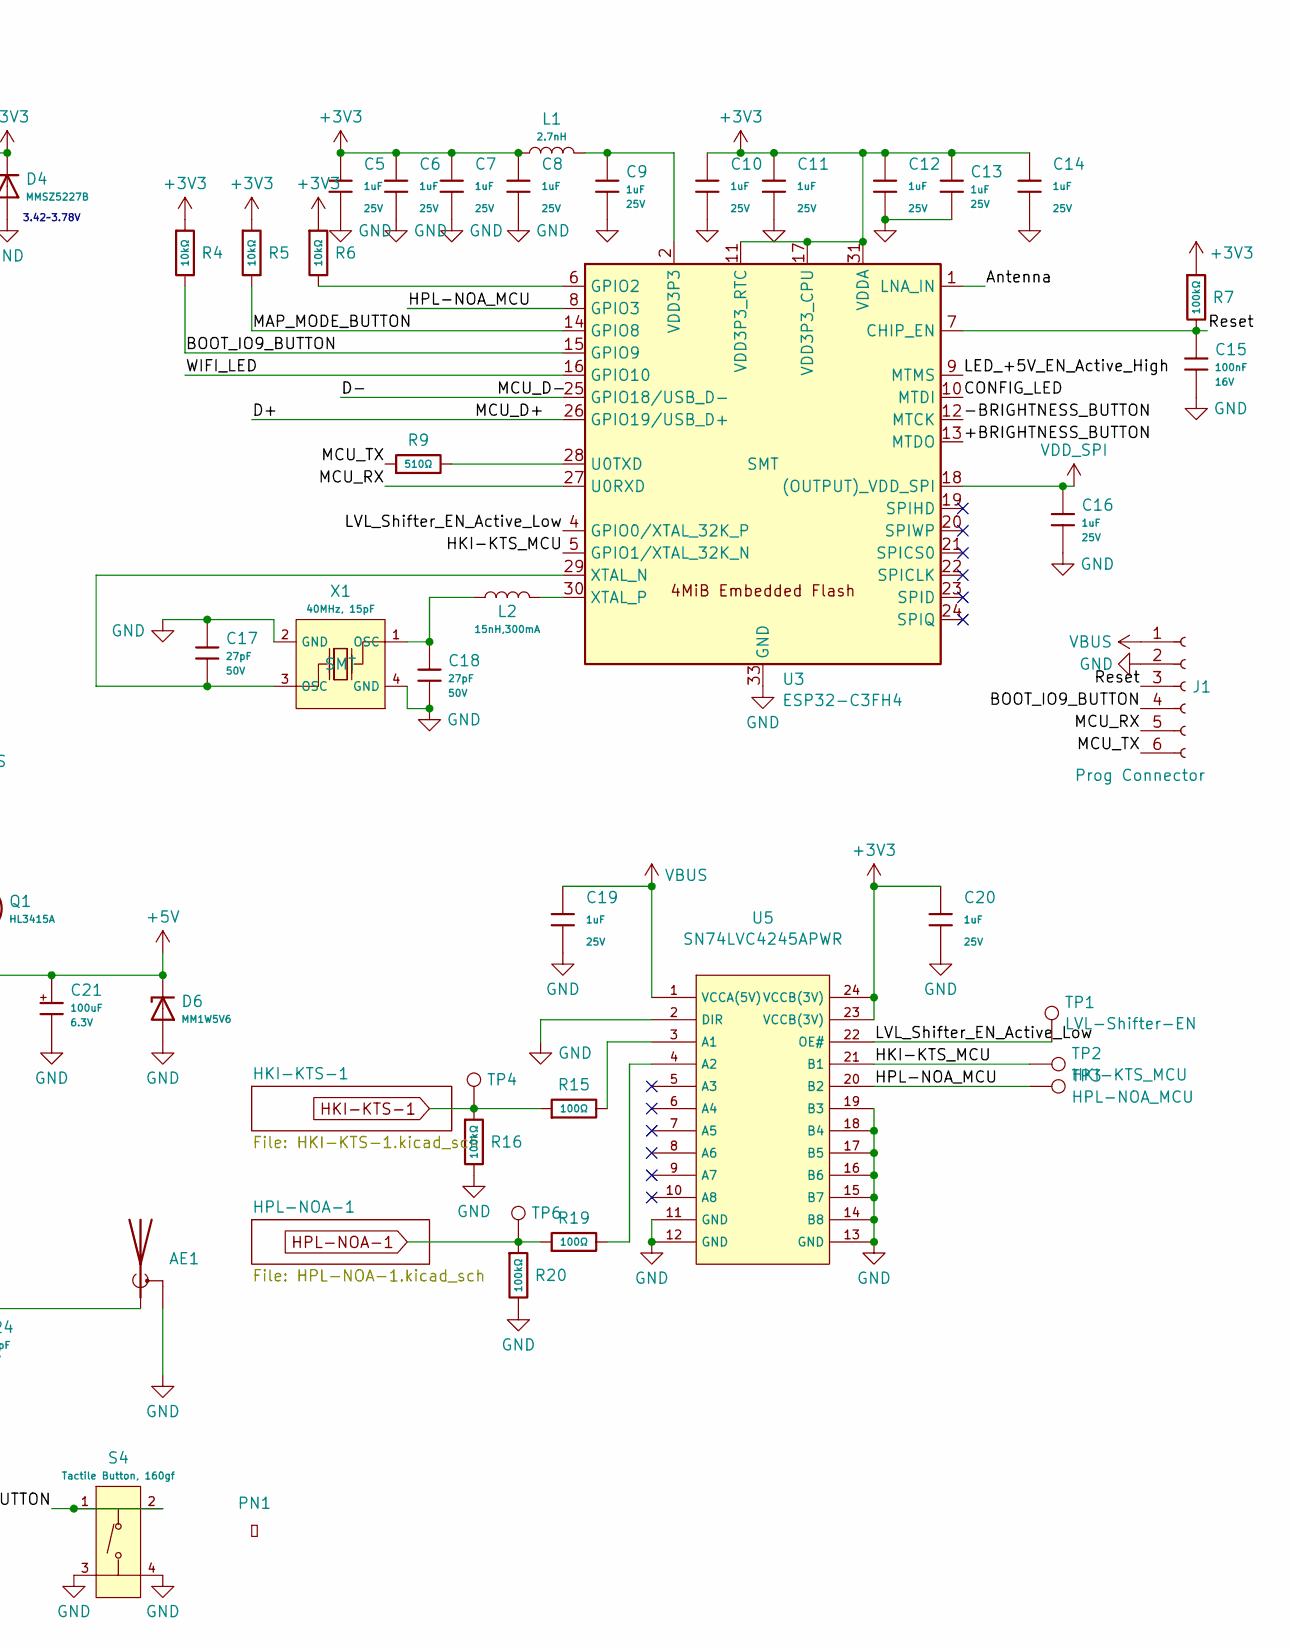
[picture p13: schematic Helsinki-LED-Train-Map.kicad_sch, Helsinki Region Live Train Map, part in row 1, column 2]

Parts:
AE1: Antenna_Shield; Inverted_F_Antenna_2.4Ghz_1.0mmPCB_TI_CC2430DB.pretty
C1: 10uF; C_CASE-A-3216-18(mm); Tolerance ±10%; Rated Voltage 16V; Part TAJA106K016RNJ; LCSC C7171
C2, C3, C5, C6, C7, C8, C9, C10, C11, C12, C13, C14, C16, C19, C20, C22: 1uF; C_0402; Voltage Rated 25V; Tolerance ±10%; Part CL05A105KA5NQNC; LCSC C52923
C4, C21: 100uF; C_CASE-B-3528-21(mm); Tolerance ±10%; Rated Voltage 6.3V; Part TAJB107K006RNJ; LCSC C16133
C15: 100nF; C_0402; Voltage Rated 16V; Tolerance ±10%; Part CL05B104KO5NNNC; LCSC C1525
C17, C18: 27pF; C_0402; Voltage Rated 50V; Tolerance ±5%; Part 0402CG270J500NT; LCSC C1557
C23, C24: 1.5pF; C_0402; Voltage Rated 50V; Part 0402CG1R5C500NT; LCSC C1552
D1, D5: SS54; D_SMA; Forward Voltage (Vf@If) 550mV@5A; Reverse Voltage (Vr) 40V; Part SS54; LCSC C22452
D2, D7, D8: Red; D_0805; Forward Voltage (VF) 1.6V~2.6V; Part NCD0805R1; LCSC C84256
D3, D6: MM1W5V6; D_SOD-123; Part MM1W5V6; LCSC C22435086
D4: MMSZ5227B; D_SOD-123; Part MMSZ5227B; LCSC C22395553
D9, D10, D11: Green; D_0805; Part KT-0805G; LCSC C2297
D12: H3V3U10B; D_DFN1006-2L; Part H3V3U10B; LCSC C20615782
F1: Polyfuse, 2A; Fuse_1206_3216Metric; LCSC C6165195
J1: Prog Connector
L1, L3: 2.7nH; L_0402; Part LQG15HS2N7S02D; LCSC C77108
L2: 15nH,300mA; L_0402; Tolerance ±5%; Part SDCL1005C15NJTDF; LCSC C27143
PN1: Part_Num_JLCPCB
Q1: HL3415A; Q_SOT-23; Part HL3415A; LCSC C28646270
Q2: MMBT3904; Q_SOT-23; Part MMBT3904; LCSC C7420353
R1, R4, R5, R6, R14: 10kΩ; R_0402; Overload Voltage (Max) 50V; Tolerance ±1%; Part 0402WGF1002TCE; LCSC C25744
R2, R3, R10, R11: 5.1kΩ; R_0402; Overload Voltage (Max) 50V; Tolerance ±1%; Part 0402WGF5101TCE; LCSC C25905
R7, R12, R16, R20, R21, R22, R23: 100kΩ; R_0402; Overload Voltage (Max) 50V; Tolerance ±1%; Part 0402WGF1003TCE; LCSC C25741
R9, R13: 510Ω; R_0402; Overload Voltage (Max) 50V; Tolerance ±1%; Part 0402WGF5100TCE; LCSC C25123
R15, R19: 100Ω; R_0402; Overload Voltage (Max) 50V; Tolerance ±1%; Part 0402WGF1000TCE; LCSC C25076
R17, R18: 15kΩ; R_0402; Overload Voltage (Max) 50V; Tolerance ±1%; Part 0402WGF1502TCE; LCSC C25756
S1, S2, S3, S4: Tactile Button, 160gf; SW-SMD_4P-L5.1-W5.1-P3.70-LS6.5-TL-2; Voltage Rating (Dc) 12V; Part TS-1187A-B-A-B; LCSC C318884
TP1: LVL-Shifter-EN; TestPoint_Pad_D1.0mm
TP2: HKI-KTS_MCU; TestPoint_Pad_D1.0mm
TP3: HPL-NOA_MCU; TestPoint_Pad_D1.0mm
TP4: STRAND-MNK_LED; TestPoint_Pad_D1.0mm
TP5: 3.3V; TestPoint_Pad_D1.0mm
TP6: NAL-NIMT_LED; TestPoint_Pad_D1.0mm
U1: XC6206P332MR; SOT-23-3_L2.9-W1.6-P1.90-LS2.8-BR; Output Voltage 3.3V; Dropout Voltage 680mV@(100mA); Part XC6206P332MR-G; LCSC C5446
U2, U4: Connector, USB-TYPE-C-16P; TYPE-C-SMD_HX-TYPE-C-16PIN; Part USB-TYPE-C-019; LCSC C2927039
U3: ESP32-C3FH4; QFN-32-1EP_5x5mm_P0.5mm_EP3.7x3.7mm_ThermalVias; Part ESP32-C3FH4; LCSC C2858491
U5: SN74LVC4245APWR; TSSOP-24_4.4x7.8mm_P0.65mm; Part SN74LVC4245APWR; LCSC C7859
X1: 40MHz, 15pF; OSC-SMD_4P-L3.2-W2.5-BL_SIT8008BI; Part X322540MPB4SI; LCSC C9010

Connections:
+3V3: C3.1, C4.1, C5.1, C6.1, C7.1, C8.1, C10.1, C11.1, C12.1, C13.1, C14.1, C20.1, D4.1, D7.2, D8.2, D9.2, L1.1, R4.1, R5.1, R6.1, R7.1, TP5.1, U1.2 (VOUT), U3.11 (VDD3P3_RTC), U3.17 (VDD3P3_CPU), U3.31 (VDDA), U3.32 (VDDA), U5.23 (VCCB(3V)), U5.24 (VCCB(3V))
+5V: C21.1, D6.1, Q1.3 (D); also elsewhere on the board
/+BRIGHTNESS_BUTTON: S2.1 (A), S2.2 (B), U3.13 (MTDO)
/-BRIGHTNESS_BUTTON: S3.1 (A), S3.2 (B), U3.12 (MTCK)
/Antenna: C23.1, D12.2, L3.1, U3.1 (LNA_IN)
/BOOT_IO9_BUTTON: J1.4, R4.2, S1.1 (A), S1.2 (B), U3.15 (GPIO9)
/CONFIG_LED: D10.2, R17.1, U3.10 (MTDI)
/D+: U2.A6 (D+), U2.B6 (D+), U3.26 (GPIO19/USB_D+)
/D-: U2.A7 (D-), U2.B7 (D-), U3.25 (GPIO18/USB_D-)
/HKI-KTS_MCU: TP2.1, U3.5 (GPIO1/XTAL_32K_N), U5.21 (B1)
/HPL-NOA_MCU: TP3.1, U3.8 (GPIO3), U5.20 (B2)
/LED_+5V_EN_Active_High: R13.2, R14.1, U3.9 (MTMS)
/LVL_Shifter_EN_Active_Low: TP1.1, U3.4 (GPIO0/XTAL_32K_P), U5.22 (OE#)
/MAP_MODE_BUTTON: R5.2, S4.1 (A), S4.2 (B), U3.14 (GPIO8)
/MCU_RX: J1.5, U3.27 (U0RXD)
/MCU_TX: J1.6, R9.1
/Reset: C15.1, J1.3, R7.2, U3.7 (CHIP_EN)
/WIFI_LED: D11.2, R18.1, U3.16 (GPIO10)
GND: AE1.2 (Shield), C1.2, C2.2, C3.2, C4.2, C5.2, C6.2, C7.2, C8.2, C9.2, C10.2, C11.2, C12.2, C13.2, C14.2, C15.2, C16.2, C17.1, C18.2, C19.2, C20.2, C21.2, C22.2, C23.2, C24.2, D3.2, D4.2, D6.2, D12.1, J1.2, Q2.2 (E), R2.2, R3.2, R10.2, R11.2, R14.2, R16.2, R20.2, R21.2, R22.2, R23.2, S1.3 (C), S1.4 (D), S2.3 (C), S2.4 (D), S3.3 (C), S3.4 (D), S4.3 (C), S4.4 (D), U1.1 (GND), U2.A12B1 (GND), U2.B12A1 (GND), U2.S1 (SHIELD), U3.33 (GND), U4.A12B1 (GND), U4.B12A1 (GND), U4.S1 (SHIELD), U5.2 (DIR), U5.11 (GND), U5.12 (GND), U5.13 (GND), U5.14 (B8), U5.15 (B7), U5.16 (B6), U5.17 (B5), U5.18 (B4), U5.19 (B3), X1.2 (GND), X1.4 (GND); also elsewhere on the board
HKI-KTS-1: R15.1, R16.1, TP4.1; also elsewhere on the board
HPL-NOA-1: R19.1, R20.1, TP6.1; also elsewhere on the board
unnamed: AE1.1 (A), C24.1, L3.2
unnamed: C9.1, L1.2, U3.2 (VDD3P3), U3.3 (VDD3P3)
unnamed: C18.1, L2.1, X1.1 (OSC)
unnamed: D1.1, D2.2, D5.1, F1.1
unnamed: D1.2, U2.A9B4 (VBUS), U2.B9A4 (VBUS)
unnamed: D2.1, R1.2
unnamed: D5.2, U4.A9B4 (VBUS), U4.B9A4 (VBUS)
unnamed: D7.1, R17.2
unnamed: D8.1, R18.2
unnamed: D9.1, R21.1
unnamed: D10.1, R22.1
unnamed: D11.1, R23.1
unnamed: Q1.1 (G), Q2.3 (C), R12.2
unnamed: C22.1, Q2.1 (B), R13.1
unnamed: R2.1, U2.A5 (CC1)
unnamed: R3.1, U2.B5 (CC2)
unnamed: R6.2, U3.6 (GPIO2)
unnamed: R9.2, U3.28 (U0TXD)
unnamed: C17.2, U3.29 (XTAL_N), X1.3 (OSC)
unnamed: L2.2, U3.30 (XTAL_P)
unnamed: R10.1, U4.A5 (CC1)
unnamed: R11.1, U4.B5 (CC2)
unnamed: R15.2, U5.3 (A1)
unnamed: R19.2, U5.4 (A2)
VBUS: C1.1, C2.1, C19.1, D3.1, F1.2, J1.1, Q1.2 (S), R1.1, R12.1, U1.3 (VIN), U5.1 (VCCA(5V))
VDD_SPI: C16.1, U3.18 ((OUTPUT)_VDD_SPI)

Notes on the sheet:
3.42~3.78V

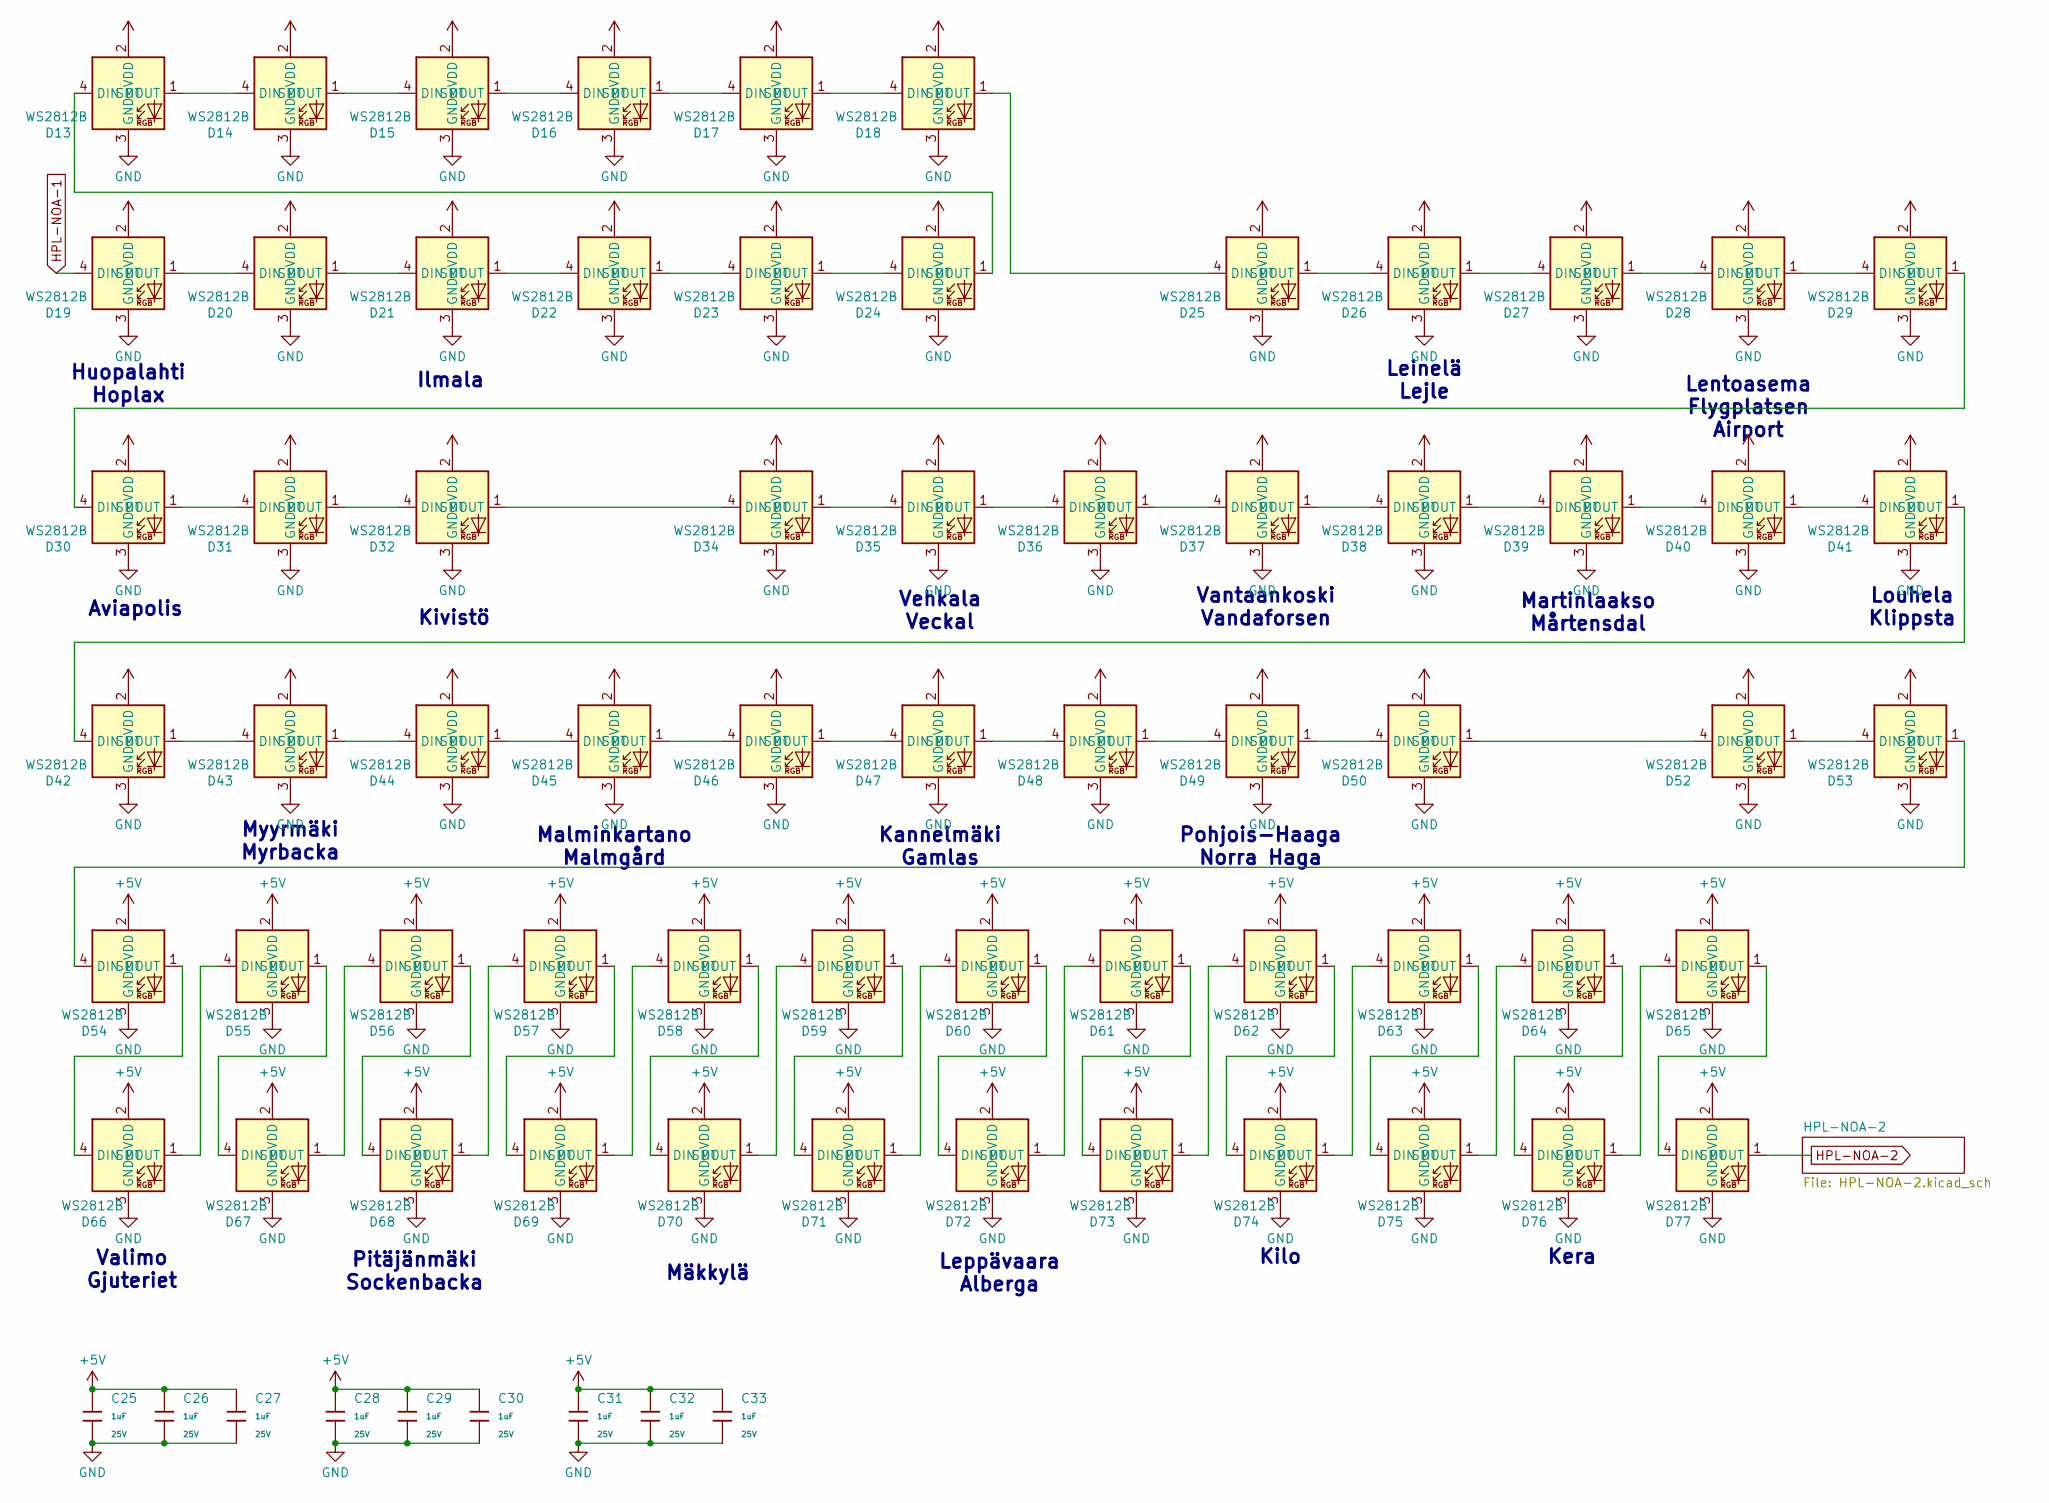
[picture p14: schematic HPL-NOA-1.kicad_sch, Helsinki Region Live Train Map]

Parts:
C25, C26, C27, C28, C29, C30, C31, C32, C33: 1uF; C_0402; Voltage Rated 25V; Tolerance ±10%; Part CL05A105KA5NQNC; LCSC C52923
D13, D14, D15, D16, D17, D18, D19, D20, D21, D22, D23, D24, D25, D26, D27, D28, D29, D30, D31, D32, D34, D35, D36, D37, D38, D39, D40, D41, D42, D43, D44, D45, D46, D47, D48, D49, D50, D52, D53, D54, D55, D56, D57, D58, D59, D60, D61, D62, D63, D64, D65, D66, D67, D68, D69, D70, D71, D72, D73, D74, D75, D76, D77: WS2812B; LED-SMD_4P-L1.6-W1.5_XL-1615RGBC-WS2812B; Part XL-1615RGBC-WS2812B; LCSC C5349954

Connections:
+5V: C25.1, C26.1, C27.1, C28.1, C29.1, C30.1, C31.1, C32.1, C33.1, D13.2 (VDD), D14.2 (VDD), D15.2 (VDD), D16.2 (VDD), D17.2 (VDD), D18.2 (VDD), D19.2 (VDD), D20.2 (VDD), D21.2 (VDD), D22.2 (VDD), D23.2 (VDD), D24.2 (VDD), D25.2 (VDD), D26.2 (VDD), D27.2 (VDD), D28.2 (VDD), D29.2 (VDD), D30.2 (VDD), D31.2 (VDD), D32.2 (VDD), D34.2 (VDD), D35.2 (VDD), D36.2 (VDD), D37.2 (VDD), D38.2 (VDD), D39.2 (VDD), D40.2 (VDD), D41.2 (VDD), D42.2 (VDD), D43.2 (VDD), D44.2 (VDD), D45.2 (VDD), D46.2 (VDD), D47.2 (VDD), D48.2 (VDD), D49.2 (VDD), D50.2 (VDD), D52.2 (VDD), D53.2 (VDD), D54.2 (VDD), D55.2 (VDD), D56.2 (VDD), D57.2 (VDD), D58.2 (VDD), D59.2 (VDD), D60.2 (VDD), D61.2 (VDD), D62.2 (VDD), D63.2 (VDD), D64.2 (VDD), D65.2 (VDD), D66.2 (VDD), D67.2 (VDD), D68.2 (VDD), D69.2 (VDD), D70.2 (VDD), D71.2 (VDD), D72.2 (VDD), D73.2 (VDD), D74.2 (VDD), D75.2 (VDD), D76.2 (VDD), D77.2 (VDD); also elsewhere on the board
GND: C25.2, C26.2, C27.2, C28.2, C29.2, C30.2, C31.2, C32.2, C33.2, D13.3 (GND), D14.3 (GND), D15.3 (GND), D16.3 (GND), D17.3 (GND), D18.3 (GND), D19.3 (GND), D20.3 (GND), D21.3 (GND), D22.3 (GND), D23.3 (GND), D24.3 (GND), D25.3 (GND), D26.3 (GND), D27.3 (GND), D28.3 (GND), D29.3 (GND), D30.3 (GND), D31.3 (GND), D32.3 (GND), D34.3 (GND), D35.3 (GND), D36.3 (GND), D37.3 (GND), D38.3 (GND), D39.3 (GND), D40.3 (GND), D41.3 (GND), D42.3 (GND), D43.3 (GND), D44.3 (GND), D45.3 (GND), D46.3 (GND), D47.3 (GND), D48.3 (GND), D49.3 (GND), D50.3 (GND), D52.3 (GND), D53.3 (GND), D54.3 (GND), D55.3 (GND), D56.3 (GND), D57.3 (GND), D58.3 (GND), D59.3 (GND), D60.3 (GND), D61.3 (GND), D62.3 (GND), D63.3 (GND), D64.3 (GND), D65.3 (GND), D66.3 (GND), D67.3 (GND), D68.3 (GND), D69.3 (GND), D70.3 (GND), D71.3 (GND), D72.3 (GND), D73.3 (GND), D74.3 (GND), D75.3 (GND), D76.3 (GND), D77.3 (GND); also elsewhere on the board
HPL-NOA-1: D19.4 (DIN); also elsewhere on the board
HPL-NOA-2: D77.1 (DOUT); also elsewhere on the board
unnamed: D13.4 (DIN), D24.1 (DOUT)
unnamed: D13.1 (DOUT), D14.4 (DIN)
unnamed: D14.1 (DOUT), D15.4 (DIN)
unnamed: D15.1 (DOUT), D16.4 (DIN)
unnamed: D16.1 (DOUT), D17.4 (DIN)
unnamed: D17.1 (DOUT), D18.4 (DIN)
unnamed: D18.1 (DOUT), D25.4 (DIN)
unnamed: D19.1 (DOUT), D20.4 (DIN)
unnamed: D20.1 (DOUT), D21.4 (DIN)
unnamed: D21.1 (DOUT), D22.4 (DIN)
unnamed: D22.1 (DOUT), D23.4 (DIN)
unnamed: D23.1 (DOUT), D24.4 (DIN)
unnamed: D25.1 (DOUT), D26.4 (DIN)
unnamed: D26.1 (DOUT), D27.4 (DIN)
unnamed: D27.1 (DOUT), D28.4 (DIN)
unnamed: D28.1 (DOUT), D29.4 (DIN)
unnamed: D29.1 (DOUT), D30.4 (DIN)
unnamed: D30.1 (DOUT), D31.4 (DIN)
unnamed: D31.1 (DOUT), D32.4 (DIN)
unnamed: D32.1 (DOUT), D34.4 (DIN)
unnamed: D34.1 (DOUT), D35.4 (DIN)
unnamed: D35.1 (DOUT), D36.4 (DIN)
unnamed: D36.1 (DOUT), D37.4 (DIN)
unnamed: D37.1 (DOUT), D38.4 (DIN)
unnamed: D38.1 (DOUT), D39.4 (DIN)
unnamed: D39.1 (DOUT), D40.4 (DIN)
unnamed: D40.1 (DOUT), D41.4 (DIN)
unnamed: D41.1 (DOUT), D42.4 (DIN)
unnamed: D42.1 (DOUT), D43.4 (DIN)
unnamed: D43.1 (DOUT), D44.4 (DIN)
unnamed: D44.1 (DOUT), D45.4 (DIN)
unnamed: D45.1 (DOUT), D46.4 (DIN)
unnamed: D46.1 (DOUT), D47.4 (DIN)
unnamed: D47.1 (DOUT), D48.4 (DIN)
unnamed: D48.1 (DOUT), D49.4 (DIN)
unnamed: D49.1 (DOUT), D50.4 (DIN)
unnamed: D50.1 (DOUT), D52.4 (DIN)
unnamed: D52.1 (DOUT), D53.4 (DIN)
unnamed: D53.1 (DOUT), D54.4 (DIN)
unnamed: D54.1 (DOUT), D66.4 (DIN)
unnamed: D55.4 (DIN), D66.1 (DOUT)
unnamed: D55.1 (DOUT), D67.4 (DIN)
unnamed: D56.4 (DIN), D67.1 (DOUT)
unnamed: D56.1 (DOUT), D68.4 (DIN)
unnamed: D57.4 (DIN), D68.1 (DOUT)
unnamed: D57.1 (DOUT), D69.4 (DIN)
unnamed: D58.4 (DIN), D69.1 (DOUT)
unnamed: D58.1 (DOUT), D70.4 (DIN)
unnamed: D59.4 (DIN), D70.1 (DOUT)
unnamed: D59.1 (DOUT), D71.4 (DIN)
unnamed: D60.4 (DIN), D71.1 (DOUT)
unnamed: D60.1 (DOUT), D72.4 (DIN)
unnamed: D61.4 (DIN), D72.1 (DOUT)
unnamed: D61.1 (DOUT), D73.4 (DIN)
unnamed: D62.4 (DIN), D73.1 (DOUT)
unnamed: D62.1 (DOUT), D74.4 (DIN)
unnamed: D63.4 (DIN), D74.1 (DOUT)
unnamed: D63.1 (DOUT), D75.4 (DIN)
unnamed: D64.4 (DIN), D75.1 (DOUT)
unnamed: D64.1 (DOUT), D76.4 (DIN)
unnamed: D65.4 (DIN), D76.1 (DOUT)
unnamed: D65.1 (DOUT), D77.4 (DIN)

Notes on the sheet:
Kannelmäki Gamlas
Leinelä Lejle
Mäkkylä
Aviapolis
Martinlaakso Mårtensdal
Pitäjänmäki Sockenbacka
Louhela Klippsta
Valimo Gjuteriet
Lentoasema Flygplatsen Airport
Malminkartano Malmgård
Pohjois-Haaga Norra Haga
Vantaankoski Vandaforsen
Kera
Myyrmäki Myrbacka
Huopalahti Hoplax
Kilo
Vehkala Veckal
Leppävaara Alberga
Ilmala
Kivistö

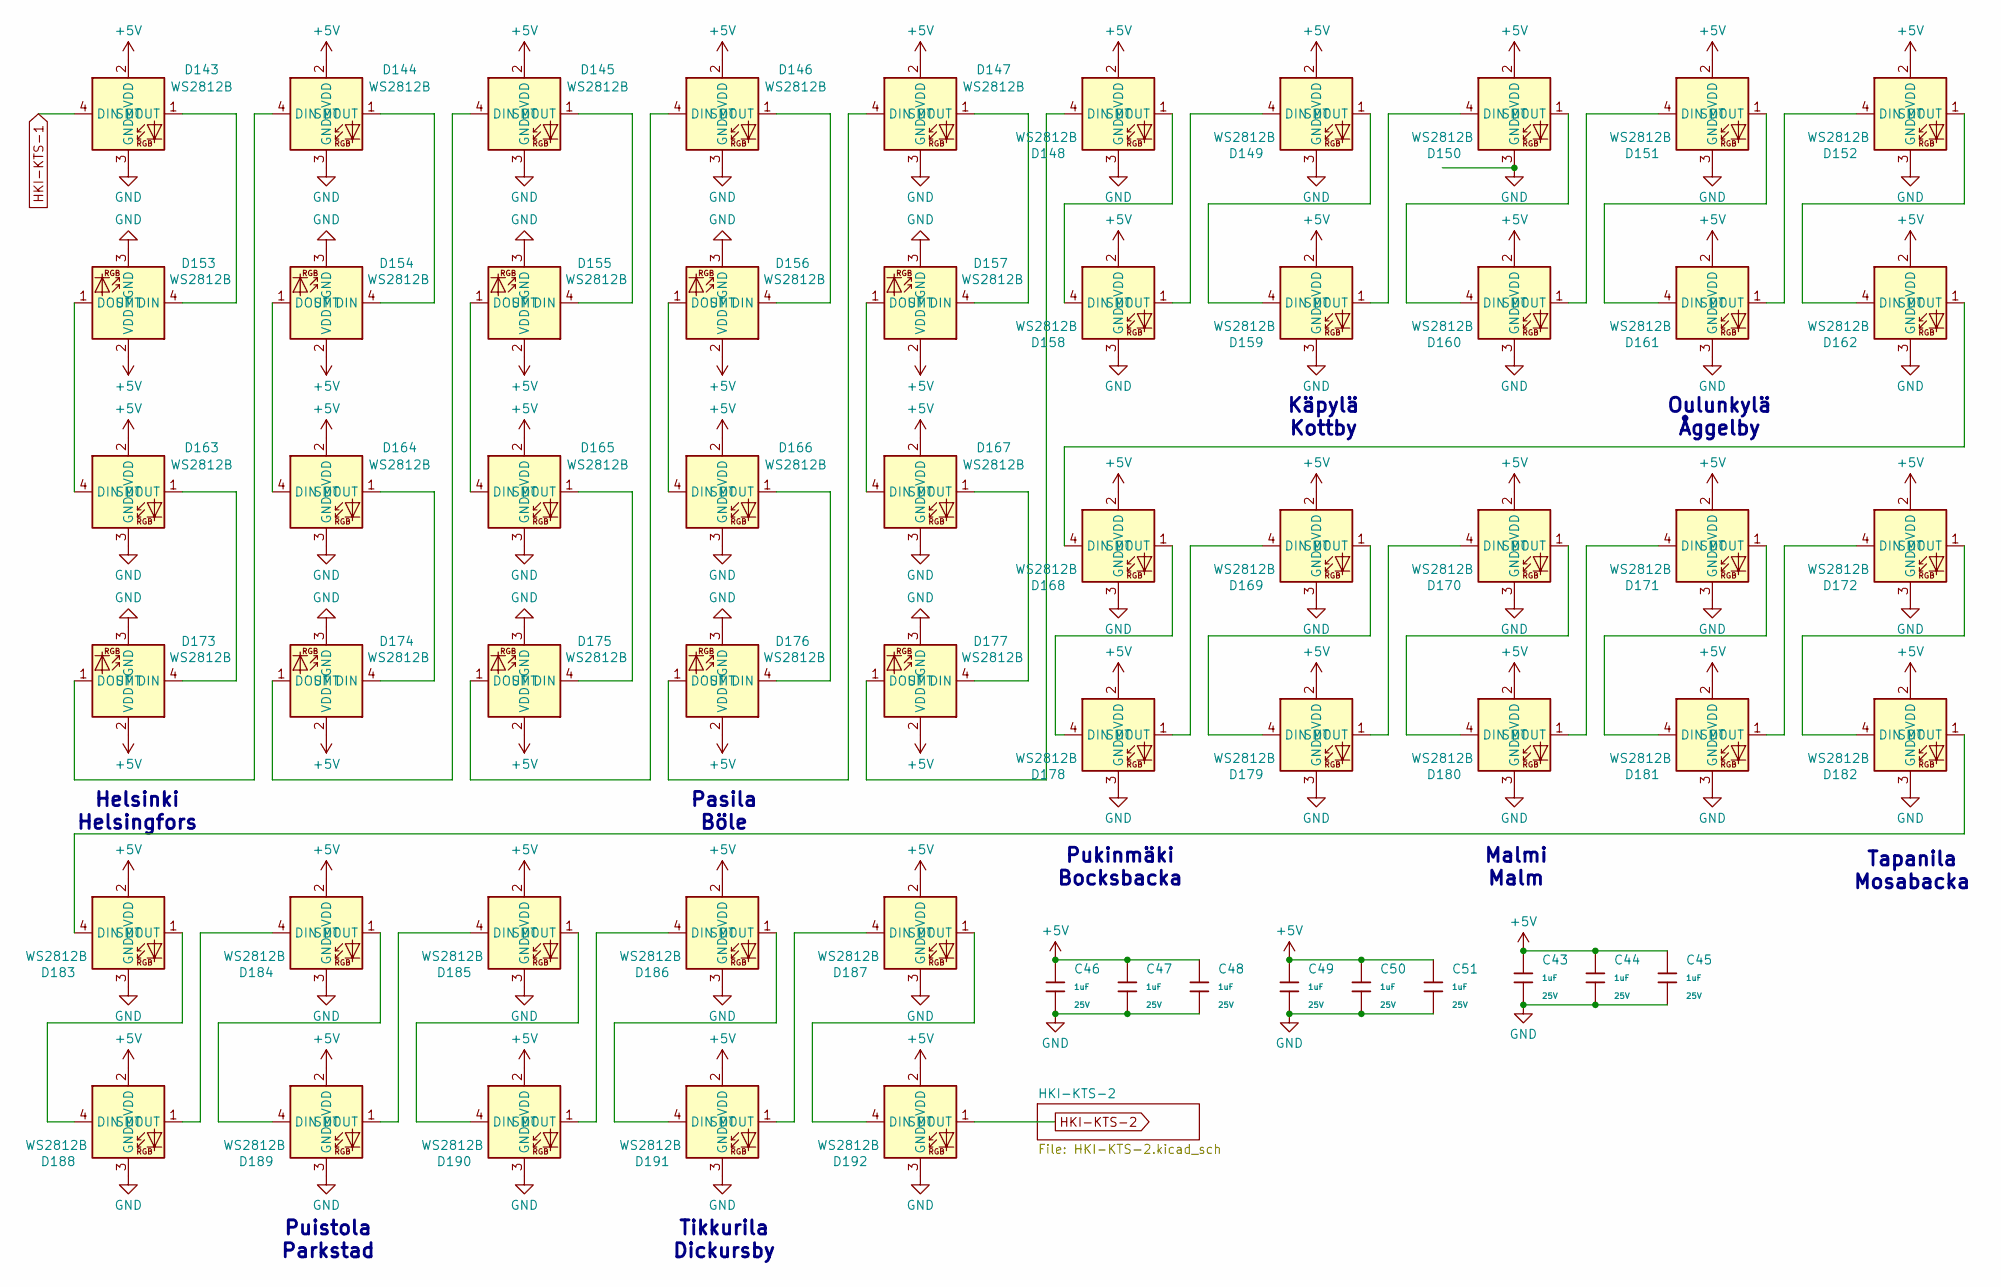
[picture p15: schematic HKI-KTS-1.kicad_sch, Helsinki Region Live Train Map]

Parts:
C43, C44, C45, C46, C47, C48, C49, C50, C51: 1uF; C_0402; Voltage Rated 25V; Tolerance ±10%; Part CL05A105KA5NQNC; LCSC C52923
D143, D144, D145, D146, D147, D148, D149, D150, D151, D152, D153, D154, D155, D156, D157, D158, D159, D160, D161, D162, D163, D164, D165, D166, D167, D168, D169, D170, D171, D172, D173, D174, D175, D176, D177, D178, D179, D180, D181, D182, D183, D184, D185, D186, D187, D188, D189, D190, D191, D192: WS2812B; LED-SMD_4P-L1.6-W1.5_XL-1615RGBC-WS2812B; Part XL-1615RGBC-WS2812B; LCSC C5349954

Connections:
+5V: C43.1, C44.1, C45.1, C46.1, C47.1, C48.1, C49.1, C50.1, C51.1, D143.2 (VDD), D144.2 (VDD), D145.2 (VDD), D146.2 (VDD), D147.2 (VDD), D148.2 (VDD), D149.2 (VDD), D150.2 (VDD), D151.2 (VDD), D152.2 (VDD), D153.2 (VDD), D154.2 (VDD), D155.2 (VDD), D156.2 (VDD), D157.2 (VDD), D158.2 (VDD), D159.2 (VDD), D160.2 (VDD), D161.2 (VDD), D162.2 (VDD), D163.2 (VDD), D164.2 (VDD), D165.2 (VDD), D166.2 (VDD), D167.2 (VDD), D168.2 (VDD), D169.2 (VDD), D170.2 (VDD), D171.2 (VDD), D172.2 (VDD), D173.2 (VDD), D174.2 (VDD), D175.2 (VDD), D176.2 (VDD), D177.2 (VDD), D178.2 (VDD), D179.2 (VDD), D180.2 (VDD), D181.2 (VDD), D182.2 (VDD), D183.2 (VDD), D184.2 (VDD), D185.2 (VDD), D186.2 (VDD), D187.2 (VDD), D188.2 (VDD), D189.2 (VDD), D190.2 (VDD), D191.2 (VDD), D192.2 (VDD); also elsewhere on the board
GND: C43.2, C44.2, C45.2, C46.2, C47.2, C48.2, C49.2, C50.2, C51.2, D143.3 (GND), D144.3 (GND), D145.3 (GND), D146.3 (GND), D147.3 (GND), D148.3 (GND), D149.3 (GND), D150.3 (GND), D151.3 (GND), D152.3 (GND), D153.3 (GND), D154.3 (GND), D155.3 (GND), D156.3 (GND), D157.3 (GND), D158.3 (GND), D159.3 (GND), D160.3 (GND), D161.3 (GND), D162.3 (GND), D163.3 (GND), D164.3 (GND), D165.3 (GND), D166.3 (GND), D167.3 (GND), D168.3 (GND), D169.3 (GND), D170.3 (GND), D171.3 (GND), D172.3 (GND), D173.3 (GND), D174.3 (GND), D175.3 (GND), D176.3 (GND), D177.3 (GND), D178.3 (GND), D179.3 (GND), D180.3 (GND), D181.3 (GND), D182.3 (GND), D183.3 (GND), D184.3 (GND), D185.3 (GND), D186.3 (GND), D187.3 (GND), D188.3 (GND), D189.3 (GND), D190.3 (GND), D191.3 (GND), D192.3 (GND); also elsewhere on the board
HKI-KTS-1: D143.4 (DIN); also elsewhere on the board
HKI-KTS-2: D192.1 (DOUT); also elsewhere on the board
unnamed: D143.1 (DOUT), D153.4 (DIN)
unnamed: D144.4 (DIN), D173.1 (DOUT)
unnamed: D144.1 (DOUT), D154.4 (DIN)
unnamed: D145.4 (DIN), D174.1 (DOUT)
unnamed: D145.1 (DOUT), D155.4 (DIN)
unnamed: D146.4 (DIN), D175.1 (DOUT)
unnamed: D146.1 (DOUT), D156.4 (DIN)
unnamed: D147.4 (DIN), D176.1 (DOUT)
unnamed: D147.1 (DOUT), D157.4 (DIN)
unnamed: D148.4 (DIN), D177.1 (DOUT)
unnamed: D148.1 (DOUT), D158.4 (DIN)
unnamed: D149.4 (DIN), D158.1 (DOUT)
unnamed: D149.1 (DOUT), D159.4 (DIN)
unnamed: D150.4 (DIN), D159.1 (DOUT)
unnamed: D150.1 (DOUT), D160.4 (DIN)
unnamed: D151.4 (DIN), D160.1 (DOUT)
unnamed: D151.1 (DOUT), D161.4 (DIN)
unnamed: D152.4 (DIN), D161.1 (DOUT)
unnamed: D152.1 (DOUT), D162.4 (DIN)
unnamed: D153.1 (DOUT), D163.4 (DIN)
unnamed: D154.1 (DOUT), D164.4 (DIN)
unnamed: D155.1 (DOUT), D165.4 (DIN)
unnamed: D156.1 (DOUT), D166.4 (DIN)
unnamed: D157.1 (DOUT), D167.4 (DIN)
unnamed: D162.1 (DOUT), D168.4 (DIN)
unnamed: D163.1 (DOUT), D173.4 (DIN)
unnamed: D164.1 (DOUT), D174.4 (DIN)
unnamed: D165.1 (DOUT), D175.4 (DIN)
unnamed: D166.1 (DOUT), D176.4 (DIN)
unnamed: D167.1 (DOUT), D177.4 (DIN)
unnamed: D168.1 (DOUT), D178.4 (DIN)
unnamed: D169.4 (DIN), D178.1 (DOUT)
unnamed: D169.1 (DOUT), D179.4 (DIN)
unnamed: D170.4 (DIN), D179.1 (DOUT)
unnamed: D170.1 (DOUT), D180.4 (DIN)
unnamed: D171.4 (DIN), D180.1 (DOUT)
unnamed: D171.1 (DOUT), D181.4 (DIN)
unnamed: D172.4 (DIN), D181.1 (DOUT)
unnamed: D172.1 (DOUT), D182.4 (DIN)
unnamed: D182.1 (DOUT), D183.4 (DIN)
unnamed: D183.1 (DOUT), D188.4 (DIN)
unnamed: D184.4 (DIN), D188.1 (DOUT)
unnamed: D184.1 (DOUT), D189.4 (DIN)
unnamed: D185.4 (DIN), D189.1 (DOUT)
unnamed: D185.1 (DOUT), D190.4 (DIN)
unnamed: D186.4 (DIN), D190.1 (DOUT)
unnamed: D186.1 (DOUT), D191.4 (DIN)
unnamed: D187.4 (DIN), D191.1 (DOUT)
unnamed: D187.1 (DOUT), D192.4 (DIN)

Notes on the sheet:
Puistola Parkstad
Malmi Malm
Tapanila Mosabacka
Pasila Böle
Oulunkylä Åggelby
Käpylä Kottby
Helsinki Helsingfors
Pukinmäki Bocksbacka
Tikkurila Dickursby

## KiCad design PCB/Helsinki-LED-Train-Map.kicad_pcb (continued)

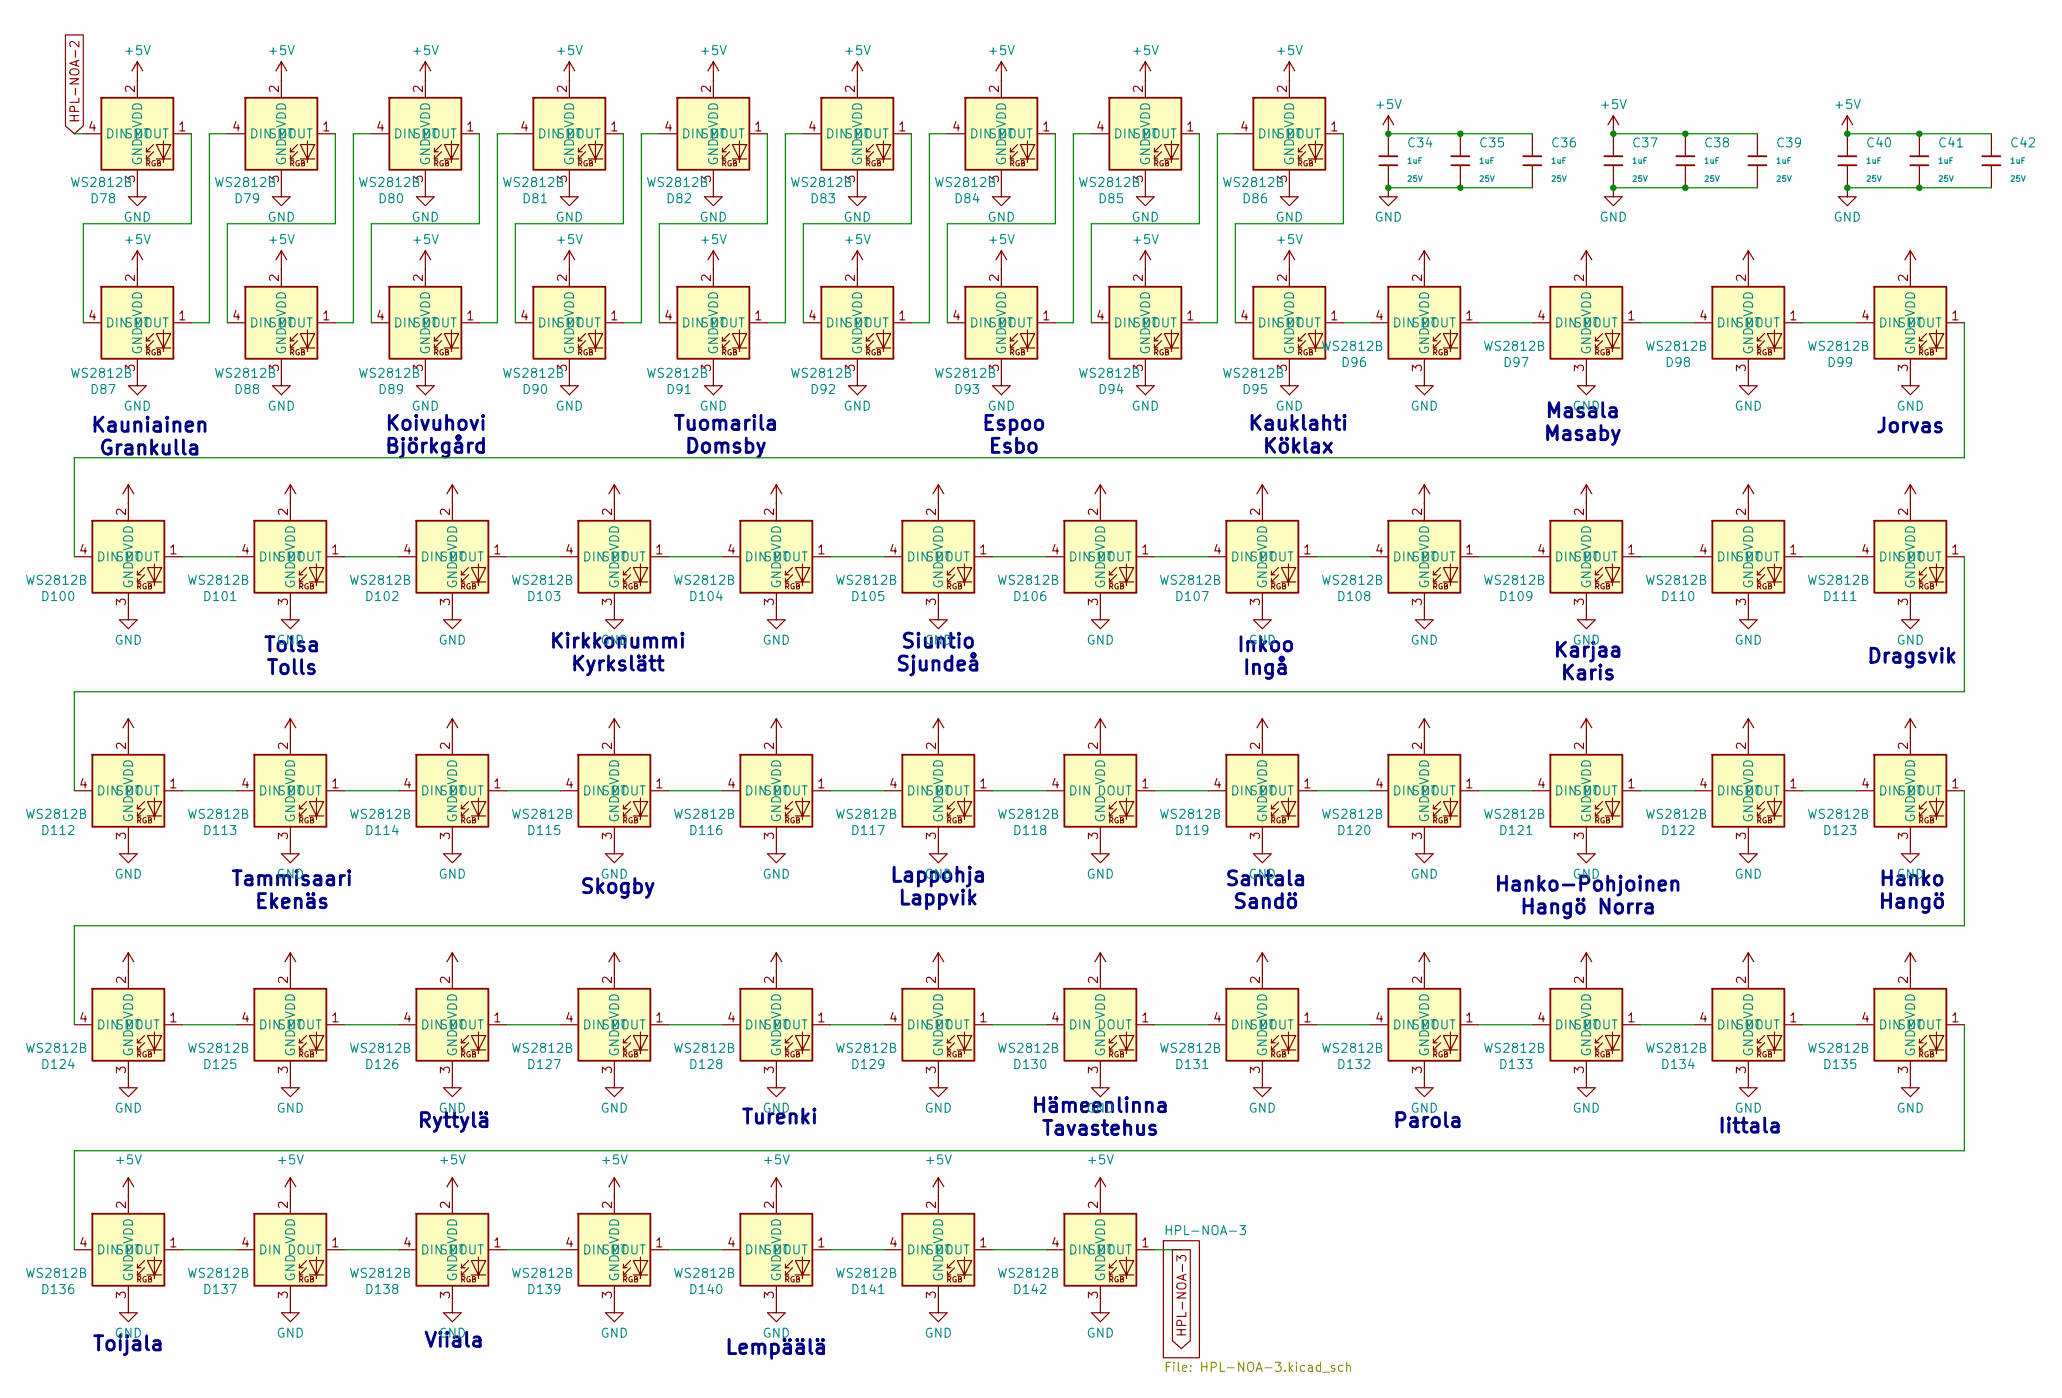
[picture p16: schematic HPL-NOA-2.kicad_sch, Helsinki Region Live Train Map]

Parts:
C34, C35, C36, C37, C38, C39, C40, C41, C42: 1uF; C_0402; Voltage Rated 25V; Tolerance ±10%; Part CL05A105KA5NQNC; LCSC C52923
D78, D79, D80, D81, D82, D83, D84, D85, D86, D87, D88, D89, D90, D91, D92, D93, D94, D95, D96, D97, D98, D99, D100, D101, D102, D103, D104, D105, D106, D107, D108, D109, D110, D111, D112, D113, D114, D115, D116, D117, D118, D119, D120, D121, D122, D123, D124, D125, D126, D127, D128, D129, D130, D131, D132, D133, D134, D135, D136, D137, D138, D139, D140, D141, D142: WS2812B; LED-SMD_4P-L1.6-W1.5_XL-1615RGBC-WS2812B; Part XL-1615RGBC-WS2812B; LCSC C5349954

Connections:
+5V: C34.1, C35.1, C36.1, C37.1, C38.1, C39.1, C40.1, C41.1, C42.1, D78.2 (VDD), D79.2 (VDD), D80.2 (VDD), D81.2 (VDD), D82.2 (VDD), D83.2 (VDD), D84.2 (VDD), D85.2 (VDD), D86.2 (VDD), D87.2 (VDD), D88.2 (VDD), D89.2 (VDD), D90.2 (VDD), D91.2 (VDD), D92.2 (VDD), D93.2 (VDD), D94.2 (VDD), D95.2 (VDD), D96.2 (VDD), D97.2 (VDD), D98.2 (VDD), D99.2 (VDD), D100.2 (VDD), D101.2 (VDD), D102.2 (VDD), D103.2 (VDD), D104.2 (VDD), D105.2 (VDD), D106.2 (VDD), D107.2 (VDD), D108.2 (VDD), D109.2 (VDD), D110.2 (VDD), D111.2 (VDD), D112.2 (VDD), D113.2 (VDD), D114.2 (VDD), D115.2 (VDD), D116.2 (VDD), D117.2 (VDD), D118.2 (VDD), D119.2 (VDD), D120.2 (VDD), D121.2 (VDD), D122.2 (VDD), D123.2 (VDD), D124.2 (VDD), D125.2 (VDD), D126.2 (VDD), D127.2 (VDD), D128.2 (VDD), D129.2 (VDD), D130.2 (VDD), D131.2 (VDD), D132.2 (VDD), D133.2 (VDD), D134.2 (VDD), D135.2 (VDD), D136.2 (VDD), D137.2 (VDD), D138.2 (VDD), D139.2 (VDD), D140.2 (VDD), D141.2 (VDD), D142.2 (VDD); also elsewhere on the board
GND: C34.2, C35.2, C36.2, C37.2, C38.2, C39.2, C40.2, C41.2, C42.2, D78.3 (GND), D79.3 (GND), D80.3 (GND), D81.3 (GND), D82.3 (GND), D83.3 (GND), D84.3 (GND), D85.3 (GND), D86.3 (GND), D87.3 (GND), D88.3 (GND), D89.3 (GND), D90.3 (GND), D91.3 (GND), D92.3 (GND), D93.3 (GND), D94.3 (GND), D95.3 (GND), D96.3 (GND), D97.3 (GND), D98.3 (GND), D99.3 (GND), D100.3 (GND), D101.3 (GND), D102.3 (GND), D103.3 (GND), D104.3 (GND), D105.3 (GND), D106.3 (GND), D107.3 (GND), D108.3 (GND), D109.3 (GND), D110.3 (GND), D111.3 (GND), D112.3 (GND), D113.3 (GND), D114.3 (GND), D115.3 (GND), D116.3 (GND), D117.3 (GND), D118.3 (GND), D119.3 (GND), D120.3 (GND), D121.3 (GND), D122.3 (GND), D123.3 (GND), D124.3 (GND), D125.3 (GND), D126.3 (GND), D127.3 (GND), D128.3 (GND), D129.3 (GND), D130.3 (GND), D131.3 (GND), D132.3 (GND), D133.3 (GND), D134.3 (GND), D135.3 (GND), D136.3 (GND), D137.3 (GND), D138.3 (GND), D139.3 (GND), D140.3 (GND), D141.3 (GND), D142.3 (GND); also elsewhere on the board
HPL-NOA-2: D78.4 (DIN); also elsewhere on the board
HPL-NOA-3: D142.1 (DOUT); also elsewhere on the board
unnamed: D78.1 (DOUT), D87.4 (DIN)
unnamed: D79.4 (DIN), D87.1 (DOUT)
unnamed: D79.1 (DOUT), D88.4 (DIN)
unnamed: D80.4 (DIN), D88.1 (DOUT)
unnamed: D80.1 (DOUT), D89.4 (DIN)
unnamed: D81.4 (DIN), D89.1 (DOUT)
unnamed: D81.1 (DOUT), D90.4 (DIN)
unnamed: D82.4 (DIN), D90.1 (DOUT)
unnamed: D82.1 (DOUT), D91.4 (DIN)
unnamed: D83.4 (DIN), D91.1 (DOUT)
unnamed: D83.1 (DOUT), D92.4 (DIN)
unnamed: D84.4 (DIN), D92.1 (DOUT)
unnamed: D84.1 (DOUT), D93.4 (DIN)
unnamed: D85.4 (DIN), D93.1 (DOUT)
unnamed: D85.1 (DOUT), D94.4 (DIN)
unnamed: D86.4 (DIN), D94.1 (DOUT)
unnamed: D86.1 (DOUT), D95.4 (DIN)
unnamed: D95.1 (DOUT), D96.4 (DIN)
unnamed: D96.1 (DOUT), D97.4 (DIN)
unnamed: D97.1 (DOUT), D98.4 (DIN)
unnamed: D98.1 (DOUT), D99.4 (DIN)
unnamed: D99.1 (DOUT), D100.4 (DIN)
unnamed: D100.1 (DOUT), D101.4 (DIN)
unnamed: D101.1 (DOUT), D102.4 (DIN)
unnamed: D102.1 (DOUT), D103.4 (DIN)
unnamed: D103.1 (DOUT), D104.4 (DIN)
unnamed: D104.1 (DOUT), D105.4 (DIN)
unnamed: D105.1 (DOUT), D106.4 (DIN)
unnamed: D106.1 (DOUT), D107.4 (DIN)
unnamed: D107.1 (DOUT), D108.4 (DIN)
unnamed: D108.1 (DOUT), D109.4 (DIN)
unnamed: D109.1 (DOUT), D110.4 (DIN)
unnamed: D110.1 (DOUT), D111.4 (DIN)
unnamed: D111.1 (DOUT), D112.4 (DIN)
unnamed: D112.1 (DOUT), D113.4 (DIN)
unnamed: D113.1 (DOUT), D114.4 (DIN)
unnamed: D114.1 (DOUT), D115.4 (DIN)
unnamed: D115.1 (DOUT), D116.4 (DIN)
unnamed: D116.1 (DOUT), D117.4 (DIN)
unnamed: D117.1 (DOUT), D118.4 (DIN)
unnamed: D118.1 (DOUT), D119.4 (DIN)
unnamed: D119.1 (DOUT), D120.4 (DIN)
unnamed: D120.1 (DOUT), D121.4 (DIN)
unnamed: D121.1 (DOUT), D122.4 (DIN)
unnamed: D122.1 (DOUT), D123.4 (DIN)
unnamed: D123.1 (DOUT), D124.4 (DIN)
unnamed: D124.1 (DOUT), D125.4 (DIN)
unnamed: D125.1 (DOUT), D126.4 (DIN)
unnamed: D126.1 (DOUT), D127.4 (DIN)
unnamed: D127.1 (DOUT), D128.4 (DIN)
unnamed: D128.1 (DOUT), D129.4 (DIN)
unnamed: D129.1 (DOUT), D130.4 (DIN)
unnamed: D130.1 (DOUT), D131.4 (DIN)
unnamed: D131.1 (DOUT), D132.4 (DIN)
unnamed: D132.1 (DOUT), D133.4 (DIN)
unnamed: D133.1 (DOUT), D134.4 (DIN)
unnamed: D134.1 (DOUT), D135.4 (DIN)
unnamed: D135.1 (DOUT), D136.4 (DIN)
unnamed: D136.1 (DOUT), D137.4 (DIN)
unnamed: D137.1 (DOUT), D138.4 (DIN)
unnamed: D138.1 (DOUT), D139.4 (DIN)
unnamed: D139.1 (DOUT), D140.4 (DIN)
unnamed: D140.1 (DOUT), D141.4 (DIN)
unnamed: D141.1 (DOUT), D142.4 (DIN)

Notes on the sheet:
Turenki
Inkoo Ingå
Tolsa Tolls
Hanko Hangö
Koivuhovi Björkgård
Lappohja Lappvik
Espoo Esbo
Lempäälä
Viiala
Skogby
Dragsvik
Tammisaari Ekenäs
Hämeenlinna Tavastehus
Santala Sandö
Masala Masaby
Hanko-Pohjoinen Hangö Norra
Toijala
Jorvas
Siuntio Sjundeå
Kauklahti Köklax
Tuomarila Domsby
Kauniainen Grankulla
Ryttylä
Kirkkonummi Kyrkslätt
Iittala
Parola
Karjaa Karis

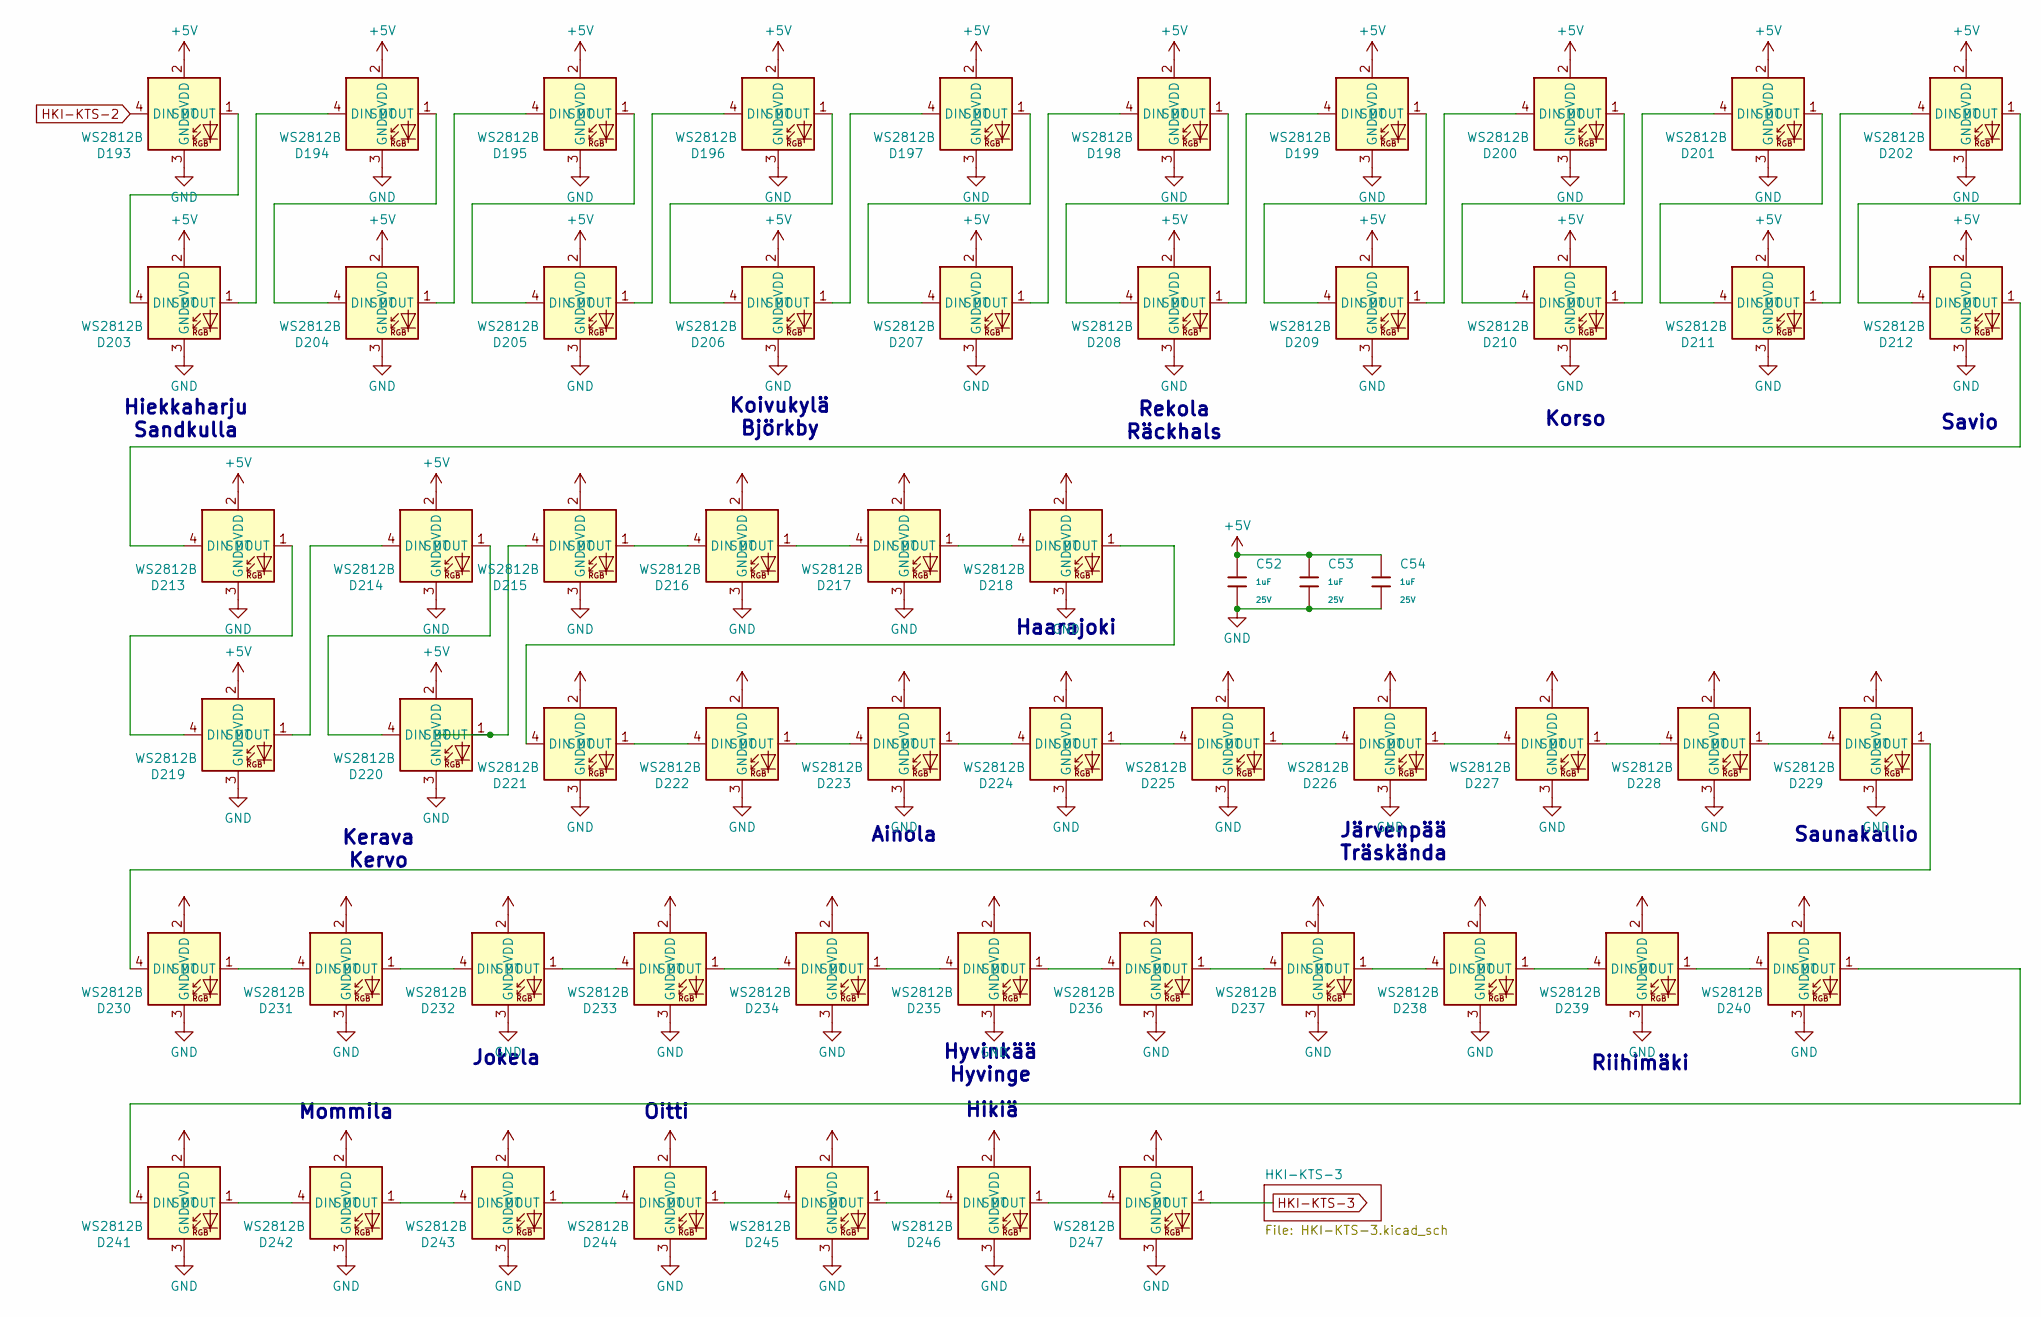
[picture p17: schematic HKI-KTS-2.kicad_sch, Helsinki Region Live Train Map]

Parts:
C52, C53, C54: 1uF; C_0402; Voltage Rated 25V; Tolerance ±10%; Part CL05A105KA5NQNC; LCSC C52923
D193, D194, D195, D196, D197, D198, D199, D200, D201, D202, D203, D204, D205, D206, D207, D208, D209, D210, D211, D212, D213, D214, D215, D216, D217, D218, D219, D220, D221, D222, D223, D224, D225, D226, D227, D228, D229, D230, D231, D232, D233, D234, D235, D236, D237, D238, D239, D240, D241, D242, D243, D244, D245, D246, D247: WS2812B; LED-SMD_4P-L1.6-W1.5_XL-1615RGBC-WS2812B; Part XL-1615RGBC-WS2812B; LCSC C5349954

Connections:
+5V: C52.1, C53.1, C54.1, D193.2 (VDD), D194.2 (VDD), D195.2 (VDD), D196.2 (VDD), D197.2 (VDD), D198.2 (VDD), D199.2 (VDD), D200.2 (VDD), D201.2 (VDD), D202.2 (VDD), D203.2 (VDD), D204.2 (VDD), D205.2 (VDD), D206.2 (VDD), D207.2 (VDD), D208.2 (VDD), D209.2 (VDD), D210.2 (VDD), D211.2 (VDD), D212.2 (VDD), D213.2 (VDD), D214.2 (VDD), D215.2 (VDD), D216.2 (VDD), D217.2 (VDD), D218.2 (VDD), D219.2 (VDD), D220.2 (VDD), D221.2 (VDD), D222.2 (VDD), D223.2 (VDD), D224.2 (VDD), D225.2 (VDD), D226.2 (VDD), D227.2 (VDD), D228.2 (VDD), D229.2 (VDD), D230.2 (VDD), D231.2 (VDD), D232.2 (VDD), D233.2 (VDD), D234.2 (VDD), D235.2 (VDD), D236.2 (VDD), D237.2 (VDD), D238.2 (VDD), D239.2 (VDD), D240.2 (VDD), D241.2 (VDD), D242.2 (VDD), D243.2 (VDD), D244.2 (VDD), D245.2 (VDD), D246.2 (VDD), D247.2 (VDD); also elsewhere on the board
GND: C52.2, C53.2, C54.2, D193.3 (GND), D194.3 (GND), D195.3 (GND), D196.3 (GND), D197.3 (GND), D198.3 (GND), D199.3 (GND), D200.3 (GND), D201.3 (GND), D202.3 (GND), D203.3 (GND), D204.3 (GND), D205.3 (GND), D206.3 (GND), D207.3 (GND), D208.3 (GND), D209.3 (GND), D210.3 (GND), D211.3 (GND), D212.3 (GND), D213.3 (GND), D214.3 (GND), D215.3 (GND), D216.3 (GND), D217.3 (GND), D218.3 (GND), D219.3 (GND), D220.3 (GND), D221.3 (GND), D222.3 (GND), D223.3 (GND), D224.3 (GND), D225.3 (GND), D226.3 (GND), D227.3 (GND), D228.3 (GND), D229.3 (GND), D230.3 (GND), D231.3 (GND), D232.3 (GND), D233.3 (GND), D234.3 (GND), D235.3 (GND), D236.3 (GND), D237.3 (GND), D238.3 (GND), D239.3 (GND), D240.3 (GND), D241.3 (GND), D242.3 (GND), D243.3 (GND), D244.3 (GND), D245.3 (GND), D246.3 (GND), D247.3 (GND); also elsewhere on the board
HKI-KTS-2: D193.4 (DIN); also elsewhere on the board
HKI-KTS-3: D247.1 (DOUT); also elsewhere on the board
unnamed: D193.1 (DOUT), D203.4 (DIN)
unnamed: D194.4 (DIN), D203.1 (DOUT)
unnamed: D194.1 (DOUT), D204.4 (DIN)
unnamed: D195.4 (DIN), D204.1 (DOUT)
unnamed: D195.1 (DOUT), D205.4 (DIN)
unnamed: D196.4 (DIN), D205.1 (DOUT)
unnamed: D196.1 (DOUT), D206.4 (DIN)
unnamed: D197.4 (DIN), D206.1 (DOUT)
unnamed: D197.1 (DOUT), D207.4 (DIN)
unnamed: D198.4 (DIN), D207.1 (DOUT)
unnamed: D198.1 (DOUT), D208.4 (DIN)
unnamed: D199.4 (DIN), D208.1 (DOUT)
unnamed: D199.1 (DOUT), D209.4 (DIN)
unnamed: D200.4 (DIN), D209.1 (DOUT)
unnamed: D200.1 (DOUT), D210.4 (DIN)
unnamed: D201.4 (DIN), D210.1 (DOUT)
unnamed: D201.1 (DOUT), D211.4 (DIN)
unnamed: D202.4 (DIN), D211.1 (DOUT)
unnamed: D202.1 (DOUT), D212.4 (DIN)
unnamed: D212.1 (DOUT), D213.4 (DIN)
unnamed: D213.1 (DOUT), D219.4 (DIN)
unnamed: D214.4 (DIN), D219.1 (DOUT)
unnamed: D214.1 (DOUT), D220.4 (DIN)
unnamed: D215.4 (DIN), D220.1 (DOUT)
unnamed: D215.1 (DOUT), D216.4 (DIN)
unnamed: D216.1 (DOUT), D217.4 (DIN)
unnamed: D217.1 (DOUT), D218.4 (DIN)
unnamed: D218.1 (DOUT), D221.4 (DIN)
unnamed: D221.1 (DOUT), D222.4 (DIN)
unnamed: D222.1 (DOUT), D223.4 (DIN)
unnamed: D223.1 (DOUT), D224.4 (DIN)
unnamed: D224.1 (DOUT), D225.4 (DIN)
unnamed: D225.1 (DOUT), D226.4 (DIN)
unnamed: D226.1 (DOUT), D227.4 (DIN)
unnamed: D227.1 (DOUT), D228.4 (DIN)
unnamed: D228.1 (DOUT), D229.4 (DIN)
unnamed: D229.1 (DOUT), D230.4 (DIN)
unnamed: D230.1 (DOUT), D231.4 (DIN)
unnamed: D231.1 (DOUT), D232.4 (DIN)
unnamed: D232.1 (DOUT), D233.4 (DIN)
unnamed: D233.1 (DOUT), D234.4 (DIN)
unnamed: D234.1 (DOUT), D235.4 (DIN)
unnamed: D235.1 (DOUT), D236.4 (DIN)
unnamed: D236.1 (DOUT), D237.4 (DIN)
unnamed: D237.1 (DOUT), D238.4 (DIN)
unnamed: D238.1 (DOUT), D239.4 (DIN)
unnamed: D239.1 (DOUT), D240.4 (DIN)
unnamed: D240.1 (DOUT), D241.4 (DIN)
unnamed: D241.1 (DOUT), D242.4 (DIN)
unnamed: D242.1 (DOUT), D243.4 (DIN)
unnamed: D243.1 (DOUT), D244.4 (DIN)
unnamed: D244.1 (DOUT), D245.4 (DIN)
unnamed: D245.1 (DOUT), D246.4 (DIN)
unnamed: D246.1 (DOUT), D247.4 (DIN)

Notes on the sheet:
Rekola Räckhals
Oitti
Kerava Kervo
Savio
Järvenpää Träskända
Riihimäki
Ainola
Jokela
Haarajoki
Saunakallio
Hiekkaharju Sandkulla
Mommila
Koivukylä Björkby
Korso
Hyvinkää Hyvinge
Hikiä

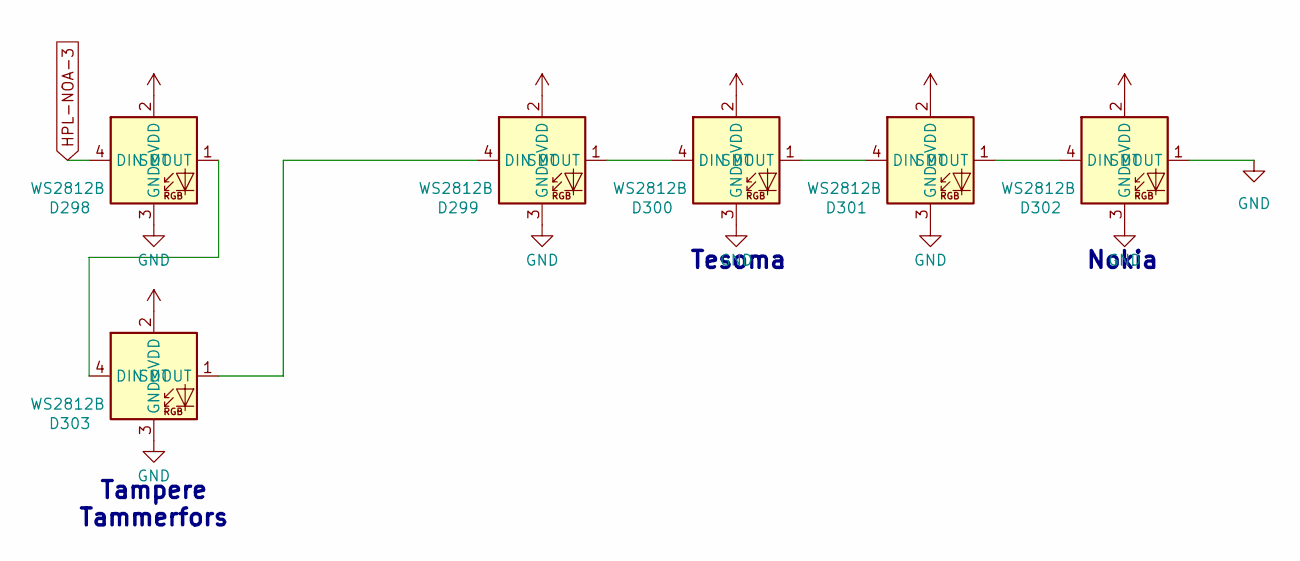
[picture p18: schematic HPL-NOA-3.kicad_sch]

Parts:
D298, D299, D300, D301, D302, D303: WS2812B; LED-SMD_4P-L1.6-W1.5_XL-1615RGBC-WS2812B; Part XL-1615RGBC-WS2812B; LCSC C5349954

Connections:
+5V: D298.2 (VDD), D299.2 (VDD), D300.2 (VDD), D301.2 (VDD), D302.2 (VDD), D303.2 (VDD); also elsewhere on the board
GND: D298.3 (GND), D299.3 (GND), D300.3 (GND), D301.3 (GND), D302.1 (DOUT), D302.3 (GND), D303.3 (GND); also elsewhere on the board
HPL-NOA-3: D298.4 (DIN); also elsewhere on the board
unnamed: D298.1 (DOUT), D303.4 (DIN)
unnamed: D299.4 (DIN), D303.1 (DOUT)
unnamed: D299.1 (DOUT), D300.4 (DIN)
unnamed: D300.1 (DOUT), D301.4 (DIN)
unnamed: D301.1 (DOUT), D302.4 (DIN)

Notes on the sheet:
Tesoma
Nokia
Tampere Tammerfors

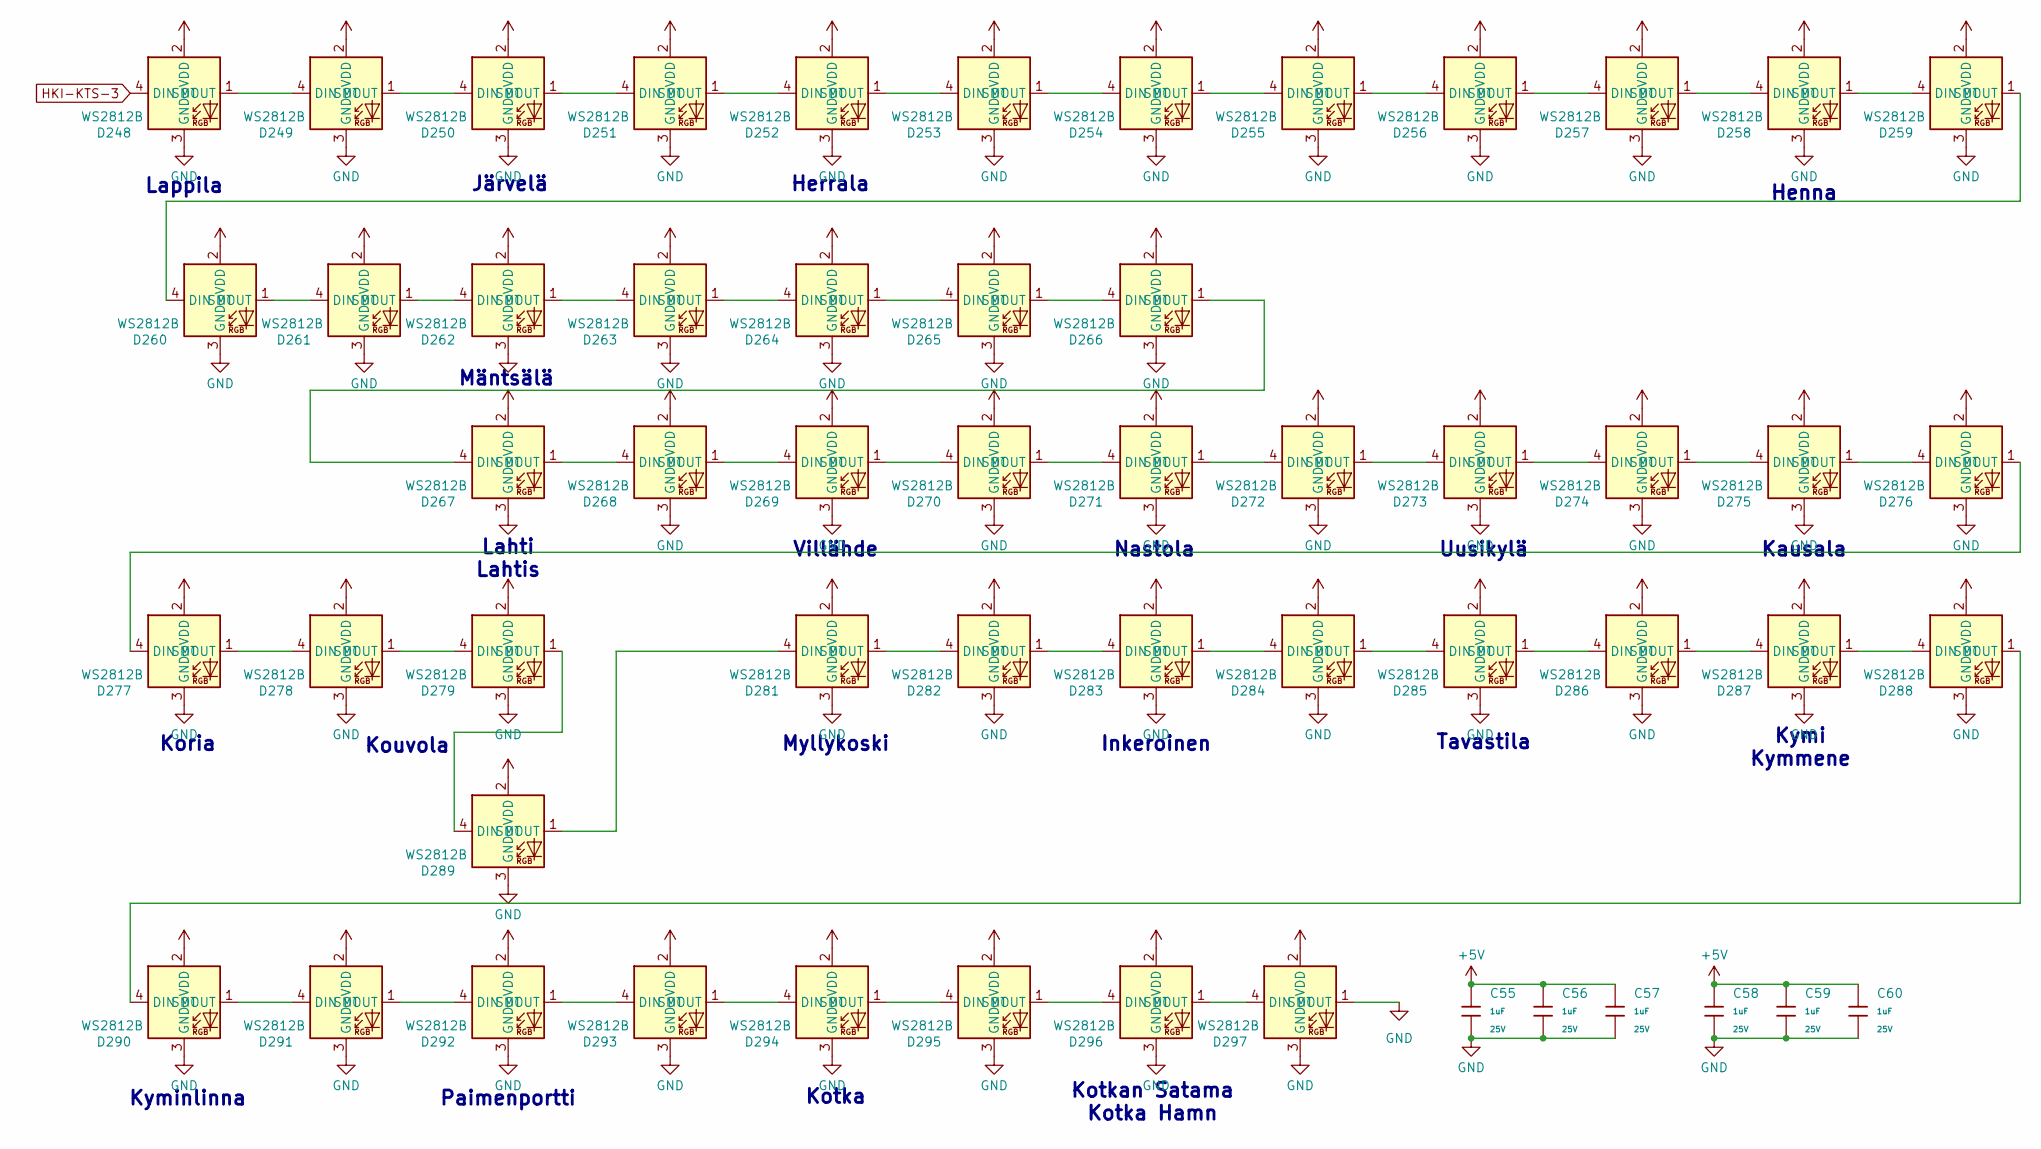
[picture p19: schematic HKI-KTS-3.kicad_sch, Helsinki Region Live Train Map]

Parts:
C55, C56, C57, C58, C59, C60: 1uF; C_0402; Voltage Rated 25V; Tolerance ±10%; Part CL05A105KA5NQNC; LCSC C52923
D248, D249, D250, D251, D252, D253, D254, D255, D256, D257, D258, D259, D260, D261, D262, D263, D264, D265, D266, D267, D268, D269, D270, D271, D272, D273, D274, D275, D276, D277, D278, D279, D281, D282, D283, D284, D285, D286, D287, D288, D289, D290, D291, D292, D293, D294, D295, D296, D297: WS2812B; LED-SMD_4P-L1.6-W1.5_XL-1615RGBC-WS2812B; Part XL-1615RGBC-WS2812B; LCSC C5349954

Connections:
+5V: C55.1, C56.1, C57.1, C58.1, C59.1, C60.1, D248.2 (VDD), D249.2 (VDD), D250.2 (VDD), D251.2 (VDD), D252.2 (VDD), D253.2 (VDD), D254.2 (VDD), D255.2 (VDD), D256.2 (VDD), D257.2 (VDD), D258.2 (VDD), D259.2 (VDD), D260.2 (VDD), D261.2 (VDD), D262.2 (VDD), D263.2 (VDD), D264.2 (VDD), D265.2 (VDD), D266.2 (VDD), D267.2 (VDD), D268.2 (VDD), D269.2 (VDD), D270.2 (VDD), D271.2 (VDD), D272.2 (VDD), D273.2 (VDD), D274.2 (VDD), D275.2 (VDD), D276.2 (VDD), D277.2 (VDD), D278.2 (VDD), D279.2 (VDD), D281.2 (VDD), D282.2 (VDD), D283.2 (VDD), D284.2 (VDD), D285.2 (VDD), D286.2 (VDD), D287.2 (VDD), D288.2 (VDD), D289.2 (VDD), D290.2 (VDD), D291.2 (VDD), D292.2 (VDD), D293.2 (VDD), D294.2 (VDD), D295.2 (VDD), D296.2 (VDD), D297.2 (VDD); also elsewhere on the board
GND: C55.2, C56.2, C57.2, C58.2, C59.2, C60.2, D248.3 (GND), D249.3 (GND), D250.3 (GND), D251.3 (GND), D252.3 (GND), D253.3 (GND), D254.3 (GND), D255.3 (GND), D256.3 (GND), D257.3 (GND), D258.3 (GND), D259.3 (GND), D260.3 (GND), D261.3 (GND), D262.3 (GND), D263.3 (GND), D264.3 (GND), D265.3 (GND), D266.3 (GND), D267.3 (GND), D268.3 (GND), D269.3 (GND), D270.3 (GND), D271.3 (GND), D272.3 (GND), D273.3 (GND), D274.3 (GND), D275.3 (GND), D276.3 (GND), D277.3 (GND), D278.3 (GND), D279.3 (GND), D281.3 (GND), D282.3 (GND), D283.3 (GND), D284.3 (GND), D285.3 (GND), D286.3 (GND), D287.3 (GND), D288.3 (GND), D289.3 (GND), D290.3 (GND), D291.3 (GND), D292.3 (GND), D293.3 (GND), D294.3 (GND), D295.3 (GND), D296.3 (GND), D297.1 (DOUT), D297.3 (GND); also elsewhere on the board
HKI-KTS-3: D248.4 (DIN); also elsewhere on the board
unnamed: D248.1 (DOUT), D249.4 (DIN)
unnamed: D249.1 (DOUT), D250.4 (DIN)
unnamed: D250.1 (DOUT), D251.4 (DIN)
unnamed: D251.1 (DOUT), D252.4 (DIN)
unnamed: D252.1 (DOUT), D253.4 (DIN)
unnamed: D253.1 (DOUT), D254.4 (DIN)
unnamed: D254.1 (DOUT), D255.4 (DIN)
unnamed: D255.1 (DOUT), D256.4 (DIN)
unnamed: D256.1 (DOUT), D257.4 (DIN)
unnamed: D257.1 (DOUT), D258.4 (DIN)
unnamed: D258.1 (DOUT), D259.4 (DIN)
unnamed: D259.1 (DOUT), D260.4 (DIN)
unnamed: D260.1 (DOUT), D261.4 (DIN)
unnamed: D261.1 (DOUT), D262.4 (DIN)
unnamed: D262.1 (DOUT), D263.4 (DIN)
unnamed: D263.1 (DOUT), D264.4 (DIN)
unnamed: D264.1 (DOUT), D265.4 (DIN)
unnamed: D265.1 (DOUT), D266.4 (DIN)
unnamed: D266.1 (DOUT), D267.4 (DIN)
unnamed: D267.1 (DOUT), D268.4 (DIN)
unnamed: D268.1 (DOUT), D269.4 (DIN)
unnamed: D269.1 (DOUT), D270.4 (DIN)
unnamed: D270.1 (DOUT), D271.4 (DIN)
unnamed: D271.1 (DOUT), D272.4 (DIN)
unnamed: D272.1 (DOUT), D273.4 (DIN)
unnamed: D273.1 (DOUT), D274.4 (DIN)
unnamed: D274.1 (DOUT), D275.4 (DIN)
unnamed: D275.1 (DOUT), D276.4 (DIN)
unnamed: D276.1 (DOUT), D277.4 (DIN)
unnamed: D277.1 (DOUT), D278.4 (DIN)
unnamed: D278.1 (DOUT), D279.4 (DIN)
unnamed: D279.1 (DOUT), D289.4 (DIN)
unnamed: D281.4 (DIN), D289.1 (DOUT)
unnamed: D281.1 (DOUT), D282.4 (DIN)
unnamed: D282.1 (DOUT), D283.4 (DIN)
unnamed: D283.1 (DOUT), D284.4 (DIN)
unnamed: D284.1 (DOUT), D285.4 (DIN)
unnamed: D285.1 (DOUT), D286.4 (DIN)
unnamed: D286.1 (DOUT), D287.4 (DIN)
unnamed: D287.1 (DOUT), D288.4 (DIN)
unnamed: D288.1 (DOUT), D290.4 (DIN)
unnamed: D290.1 (DOUT), D291.4 (DIN)
unnamed: D291.1 (DOUT), D292.4 (DIN)
unnamed: D292.1 (DOUT), D293.4 (DIN)
unnamed: D293.1 (DOUT), D294.4 (DIN)
unnamed: D294.1 (DOUT), D295.4 (DIN)
unnamed: D295.1 (DOUT), D296.4 (DIN)
unnamed: D296.1 (DOUT), D297.4 (DIN)

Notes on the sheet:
Villähde
Kausala
Kotkan Satama Kotka Hamn
Lahti Lahtis
Inkeroinen
Uusikylä
Myllykoski
Nastola
Paimenportti
Henna
Tavastila
Kotka
Koria
Järvelä
Kymi Kymmene
Kouvola
Herrala
Kyminlinna
Mäntsälä
Lappila

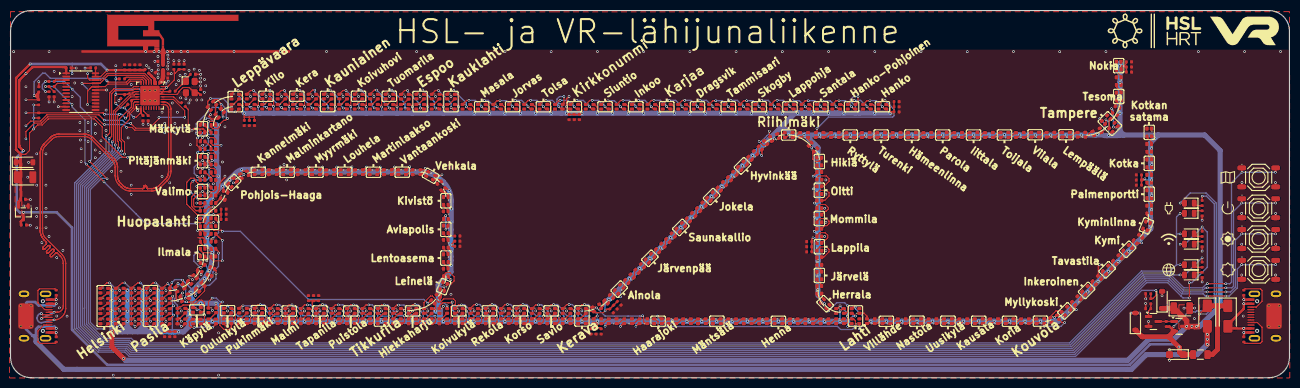
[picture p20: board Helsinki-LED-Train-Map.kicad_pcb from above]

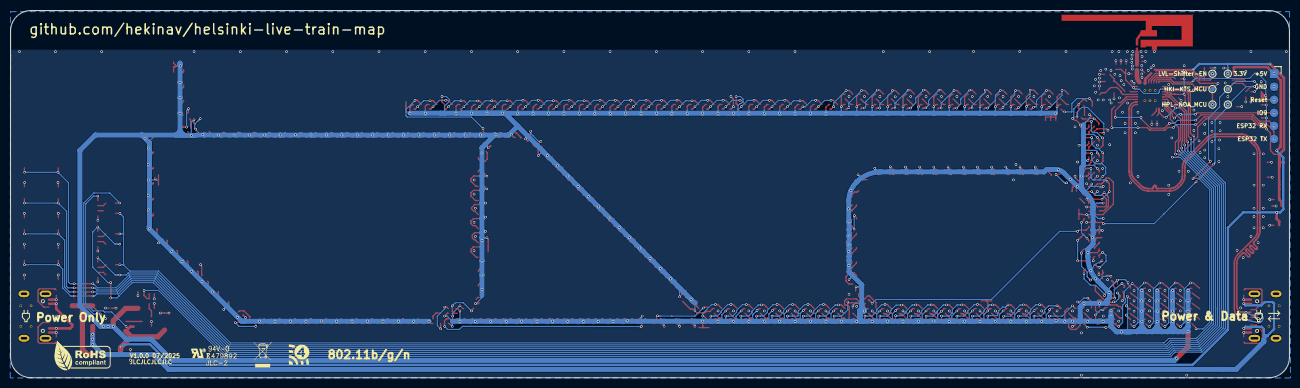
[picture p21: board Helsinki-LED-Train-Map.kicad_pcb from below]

Board: 2 copper layers, 249.0 x 71.5 mm, 407 parts (7 on the bottom side), 333 nets.

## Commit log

2025-07-06 pcb fixes
    [HKI-KTS-1.kicad_sch, HKI-KTS-2.kicad_sch, HKI-KTS-3.kicad_sch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]
2025-07-07 Chris's PCB Review
2025-07-19 pcb changes
    [HKI-KTS-1.kicad_sch, HKI-KTS-2.kicad_sch, HKI-KTS-3.kicad_sch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]
2025-07-19 readme changes
    [HKI-KTS-1.kicad_sch, HKI-KTS-2.kicad_sch, HKI-KTS-3.kicad_sch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]
2025-08-18 Simulator added
    [Auckland-LED-Train-Map.csv, HKI-KTS-1.kicad_sch, HKI-KTS-2.kicad_sch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]
2025-09-19 removed mask form on top of usb signal vias
    [Helsinki-LED-Train-Map.kicad_pcb]
2025-09-19 pcb stuff
2025-09-21 some last minute changes
    [ltm_stand.3mf, ltm_stand.step]
2025-12-18 switched to https and fixed deployment file
2025-12-21 added single led diffuser
    [XL1615-WS2812B_diffuser.3mf, XL1615-WS2812B_diffuser.FCStd, ltm_stand.3mf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]
2025-12-22 add diffuser
    [XL1615-WS2812B_diffuser.FCStd]
2025-12-23 tried to put a 3d model of the pcb on tje website
    [Helsinki-LED-Train-Map.kicad_pcb, Unnamed-Helsinki-LED-Train-Map.obj, pcb.obj]
2025-12-24 optimized the pcb but now created heavy z-fighting
2026-03-23 updated firmware and website
    [pcb.obj]
2026-03-23 zipped pcb.wrl to fit within wrangler constraints
2026-03-24 optimized /data to not use arduinojson
2026-06-30 moved firmware to new repo
    [default_4MB.csv]
2026-07-07 added blender render
    [default_4MB.csv, pcb.blend]
2026-08-16 Update debug connector
    [Helsinki-LED-Train-Map.kicad_pcb, pcb.blend]

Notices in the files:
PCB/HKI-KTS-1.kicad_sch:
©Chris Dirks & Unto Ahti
